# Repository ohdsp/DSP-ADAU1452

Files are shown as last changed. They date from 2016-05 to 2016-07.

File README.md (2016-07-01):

# [Open Hardware DSP Platform](http://www.ohdsp.org)
## ADAU145x DSP supporting ADAU1452, ADAU1451, and ADAU1450 devices
### Revision 2.0
###### DSP-ADAU1452 (KiCad 4.0.2-stable)
---
# README
### Disclaimer
Copyright Paul Janicki 2015

Licensed under the TAPR Open Hardware License (www.tapr.org/OHL)

This documentation is distributed WITHOUT ANY EXPRESS OR IMPLIED WARRANTY, INCLUDING OF MERCHANTABILITY, SATISFACTORY QUALITY AND FITNESS FOR A PARTICULAR PURPOSE.

### What is this repository for?

**Quick summary**

This is a simple self-bootable ADAU1450, ADAU1451, or ADAU1452 based DSP board with 4 I2S (TDM/left and right justified and more) input and 4 output connectors. When used with the ADAU1451 and ADAU1452 parts there are also optical and coaxial SPDIF input and output connectors. 

There is an I2C/SPI connector for connection to the Analog Devices SigmaStudio USBi to EZ-Board Adapter (ADZS-USBI2EZB) or anything that will do the same job (eg freeUSBi). The board also features master and slave SPI connectors for use with other OHDSP boards. The board has space for a self-boot EEPROM and so with the ADZS-USBI2EZB or compatible device the board can be programmed as you wish and will selfboot the last program written when enabled. 

This board forms the core of the open hardware DSP platform which is designed to be a highly customisable and flexible DSP platform. 

This repository contains the KiCad design files, manufacturing Gerber/drill files, and PDF/drawing files for this board.

### What is the project folder structure?
Most folder names are self explanatory. Starting from the top level: \
*DSP-ADAU1452*
+ *Bill of Materials*  - This contains the bill of materials in CVS, LibreOffice Calc and XML formats
+ *Drawings*
    + *PCB* - This contains SVG and PDF outputs of PCB copper layers and assembly drawings
    + *Schematics* - This contains the PDF schematic drawing
+ *Gerbers* - This contains the PCB Gerbers and drill drawings for manufacture, there is also a zip file ready to send to most manufacturers
+ *KiCad* - This contains the original KiCad schematic and PCB design files

### How do I get set up?

**Summary of set up**

1. Set your self up a directory on a local disk, something simple will make life easier (eg C:\Electronics on Windows as used here), but anywhere will do just fine.
2. Download the Kicad-Libs from [https://github.com/ohdsp/KiCad-Libs](https://github.com/ohdsp/KiCad-Libs) and place in C:\Electronics\Kicad-Libs (or your chosen folder) 
3. Create a OHDSP subdirectory in C:\Electronics (so C:\Electronics\OHDSP)
3. Download this project to C:\Electronics\OHDSP\DSP-ADAU1452
4. Fire up Kicad
5. Open the main project file C:\Electronics\OHDSP\DSP-ADAU1452\Schematics\DSP-ADAU1452.pro
6. (Optional) Setup Pcbnew component library as below.
7. Do as you wish with the project, just keep it under the TAPR Open Hardware License.

Make sure your git setup doesn't exclude files used in the project (like .LIB files) or things may go wrong down the line.

**KiCad Library Configuration**

Note that you need to setup a Pcbnew library, but the eeschema libraries should work without any changes if you followed the instructions above.

To setup Pcbnew libraries:

In Pcbnew go to Preferences -> Footprint Libraries Manager. Under Global Libraries tab in the top list check if there is a nickname "MyKiCadLibs-Footprints" (usually at the end of the list). If there is but it points to the wrong place then change the Library Path to point to MyKiCadLibs-Footprints (eg C:\Electronics\KiCad-Libs\MyKiCadLibs-Footprints.pretty) folder for your setup. If this is missing you can use "Append with Wizard", choose "Files on my computer", click next, browse to library location (eg C:\Electronics\KiCad-Libs\MyKiCadLibs-Footprints.pretty) and select the folder MyKiCadLibs-Footprints.pretty, click next, check the Status column states OK and the Format is KiCad (if not re-download the library) and click next, then select "To global library configuration..." and click Finish.

To setup eeschema component libraries:
Either from KiCad project window go to Tools -> Run Library Editor OR under eeschema, go to Tools -> Library Editor. Then Preferences -> Component Libraries.

The top section "Component Library Files" should ideally contain only two libraries, the "power" library that ships with KiCad and "MyKiCadLibs-Lib" available from above. To setup MyKiCadLibs-Lib as a relative path under the "User defined search path" click add. Browse to the location of KiCad-Libs you download above (eg C:\Electronics\KiCad-Libs) and click "Select Folder". Say yes to add a relative path. Under component library files click add, browse to the KiCad-libs again (eg C:\Electronics\KiCad-Libs), select file "MyKiCadLibs-Lib.lib" and click open. MyKiCadLibs-lib should appear in the component library list with no path as it will be using the user defined search path set in the box below.

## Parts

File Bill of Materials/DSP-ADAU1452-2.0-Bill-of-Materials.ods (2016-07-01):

DSP-ADAU1452-2.0 of Materials – Revision 2.0
25 May 2016
Reference | Quantity | Footprint | Value | Description | Voltage | Type | Tolerance | Size | Current | Power
C205 C214 C231 C250 C265 C304 C327 C401 C501 C504 | 10 | SMD-0805 | 100p | 'Ceramic capacitor | '50V | 'C0G | '5% | '0805 | ' | '
C206 C232 C251 C318 C324 C336 C403 | 7 | CAP-TH-D6.3mmP2.5mm | 220u | 'Low impedance aluminium electrolytic capacitor - Panasonic FC, FR or similar | '10V | '2.5mm pitch, 6.3mm diameter | ' | ' | ' | '
C207 C234 C267 C313 C315 C316 C322 C334 C405 C502 C505 | 11 | SMD-0805 | 22u | 'Ceramic capacitor | '10V | 'X5R | '20% | '0805 | ' | '
C201 C208 C210 C212 C218 C233 C235 C236 C239 C243 C253 C264 C302 C307 C310 C314 C317 C319 C320 C323 C326 C329 C333 C338 C402 C406 C412 C413 C414 C416 C417 C503 C506 | 33 | SMD-0805 | 100n | 'Ceramic capacitor | '50V | 'X7R | '10% | '0805 | ' | '
C209 C211 C216 C256 C266 C321 C325 C328 C337 C339 C404 C410 C411 | 13 | SMD-0805 | 10u | 'Ceramic capacitor | '10V | 'X5R | '20% | '0805 | ' | '
C213 C219 C223 C228 C237 C240 C242 C245 C246 C257 | 10 | SMD-0603 | 1u | 'Ceramic capacitor | '10V | 'X7R | '10% | '0603 | ' | '
C215 C221 C226 C229 C238 C241 C244 C247 C248 C258 C268 | 11 | SMD-0603 | 100n | 'Ceramic capacitor | '50V | 'X7R | '10% | '0603 | ' | '
C217 C222 C227 C230 C249 C260 | 6 | SMD-0603 | 10n | 'Ceramic capacitor | '50V | 'X7R | '10% | '0603 | ' | '
C224 | 1 | SMD-0603 | 5n6 | 'Ceramic capacitor | '50V | 'X7R | '10% | '0603 | ' | '
C225 | 1 | SMD-0603 | 150p | 'Ceramic capacitor | '50V | 'C0G | '5% | '0603 | ' | '
C252 | 1 | SMD-0805 | 22u | 'Ceramic capacitor | '10V | 'X5R | '20% | ' | ' | '
C254 C261 | 2 | SMD-0805 | 33p | 'Ceramic capacitor | '50V | 'C0G | '5% | '0805 | ' | '
C220 C263 C308 C415 | 4 | SMD-0805 | 10n | 'Ceramic capacitor | '50V | 'X7R | '10% | '0805 | ' | '
C303 C306 | 2 | CAP-TH-D6.3mmP2.5mm | 220u | 'Aluminium electrolytic capacitor | '16V | '2.5mm pitch, 6.3mm diameter | ' | ' | ' | '
C301 C305 C309 | 3 | SMD-0805 | 22u | 'Ceramic capacitor | '25V | 'X5R | '20% | '0805 | ' | '
C311 C312 | 2 | SMD-0805 | N/F | 'Ceramic capacitor | '16V | 'X7R | '10% | '0805 | ' | '
C407 C408 | 2 | SMD-0805 | N/F | 'Ceramic capacitor | '10V | 'X7R | '10% | '0805 | ' | '
CN401 CN402 | 2 | CONN_SIL_2_1MM | COAX | '1x2 2.54mm pitch pin header - use with 75Ohm coax | ' | ' | ' | ' | ' | '
D301 D302 | 2 | DIODE-SMA | B240A | 'B240A 2A 40V Schottky Rectifier - SMA (DO-214AC) | ' | ' | ' | ' | ' | '
D303 D305 D306 D307 D501 D502 D503 D504 D505 D506 D507 D508 D509 D510 D511 D512 | 16 | DIODE-SOD-123 | SS14L | 'SS14L 1A 40V Schottky rectifier - Sub-SMA (SOD-123) | ' | ' | ' | ' | ' | '
D304 | 1 | SMD-1206 | Green LED 1206 | 'Green LED - SMD - Vf 1.8V to 2.2V | ' | ' | ' | '1206 | ' | '
FID1 FID2 FID3 FID4 | 4 | FID-1MM-3MM | MNT_HOLE | 'Fiducial | ' | ' | ' | ' | ' | '
L201 L202 L203 L301 L401 | 5 | SMD-0805 | 600R@100MHz | 'Ferrite bead, current rating 1A or higher, 600R@100MHz | ' | ' | ' | '0805 | '=>1A | '
L302 | 1 | IND-TYS5040-HS | TYS50404R7N-10 | 'Laird Technologies TYS5040 4.7uH Inductor - 3A Irms, 3.5A Isat, 0.030ohm, 28MHz | ' | ' | ' | ' | '3A | '
MNT301 MNT302 MNT303 MNT304 | 4 | MNT_HOLE_3.2mm | MNT_HOLE | 'Mounting hole | ' | ' | ' | ' | ' | '
JP201 P202 P306 P307 | 4 | CONN_SIL_2_1MM | CONN_2x1 | '1x2 2.54mm pitch pin header | ' | ' | ' | ' | ' | '
JP401 P203 | 2 | CONN_SIL_3_1MM | CONN_3x1 | '1x3 2.54mm pitch pin header | ' | ' | ' | ' | ' | '
P304 | 1 | CONN-2WAY-2.54mm-3.81mm-SPACING | CONN_2x1 | '2 way screw terminal, any 2.54mm to 3.81mm pitch part | ' | ' | ' | ' | ' | '
P501 P502 P503 P504 P506 P507 P508 P509 P510 | 9 | CONN_DIL_2X5_BOX_1MM | CONN_02X05 | '2x5 2.54mm pitch box header | ' | ' | ' | ' | ' | '
P505 | 1 | CONN_DIL_2X6_1MM | CONN_02X06 | '2x6 2.54mm pitch box header | ' | ' | ' | ' | ' | '
P511 P512 | 2 | CONN_DIL_2X6_BOX_1MM | CONN_02X06 | '2x6 2.54mm pitch box header | ' | ' | ' | ' | ' | '
R201 R225 R542 R543 | 4 | SMD-0805 | 1k | 'Thick or thin film resistor | ' | ' | '1% | '0805 | ' | '100mW
R202 R215 R224 R237 R246 R303 R311 R401 R533 R534 | 10 | SMD-0805 | 47 | 'Thick or thin film resistor | ' | ' | '1% | '0805 | ' | '100mW
R203 R204 R205 R206 R207 R208 R209 R210 R220 R239 R243 R245 R501 R502 R503 R504 R505 R506 R507 R508 R509 R510 R511 R512 R513 R514 R515 R516 R568 R569 R570 R571 R572 R573 R574 R575 R576 R577 R578 R579 R580 R581 R582 R583 | 44 | SMD-0805 | N/F | 'Thick or thin film resistor | ' | ' | '1% | '0805 | ' | '100mW
R211 R227 R228 R229 R230 R233 R234 R235 R236 R248 R403 R404 R405 R406 R407 R413 R544 R545 R546 R547 R548 R549 R550 R551 R553 R554 R555 R557 R558 R559 R561 R562 R563 R565 R566 R567 | 36 | SMD-0805 | 75 | 'Thick or thin film resistor | ' | ' | '1% | '0805 | ' | '100mW
R217 | 1 | SMD-0805 | 12k | 'Thick or thin film resistor | ' | ' | '1% | '0805 | ' | '100mW
R218 | 1 | SMD-0805 | 3k3 | 'Thick or thin film resistor | ' | ' | '1% | '0805 | ' | '100mW
R219 | 1 | SMD-0603 | 4k3 | 'Thick or thin film resistor | ' | ' | '1% | '0603 | ' | '63mW
R221 | 1 | SMD-0805 | 3k | 'Thick or thin film resistor | ' | ' | '1% | '0805 | ' | '100mW
R222 | 1 | SMD-0805 | 3k6 | 'Thick or thin film resistor | ' | ' | '1% | '0805 | ' | '100mW
R212 R213 R214 R216 R223 R306 R517 R518 R519 R520 R521 R522 R523 R524 R525 R526 R527 R528 R529 R530 R531 R532 R541 R552 R556 R560 R564 R586 R587 | 29 | SMD-0805 | 0 | 'Thick or thin film resistor | ' | ' | '1% | '0805 | ' | '100mW
R226 R231 R241 R411 | 4 | SMD-0805 | 100 | 'Thick or thin film resistor | ' | ' | '1% | '0805 | ' | '100mW
R232 | 1 | SMD-0805 | 100k | 'Thick or thin film resistor | ' | ' | '1% | '0805 | ' | '100mW
R238 R240 R242 R302 R402 R408 R409 | 7 | SMD-0805 | 10k | 'Thick or thin film resistor | ' | ' | '1% | '0805 | ' | '100mW
R244 R247 R310 R584 R585 | 5 | SMD-0805 | 1 | 'Thick or thin film resistor | ' | ' | '1% | '0805 | ' | '100mW
R301 | 1 | SMD-0805 | 16k | 'Thick or thin film resistor | ' | ' | '1% | '0805 | ' | '100mW
R304 | 1 | SMD-0805 | 24k | 'Thick or thin film resistor | ' | ' | '1% | '0805 | ' | '100mW
R305 | 1 | SMD-0805 | 15k | 'Thick or thin film resistor | ' | ' | '1% | '0805 | ' | '100mW
R309 | 1 | SMD-0805 | 470 | 'Thick or thin film resistor | ' | ' | '1% | '0805 | ' | '100mW
R410 | 1 | SMD-0805 | 360 | 'Thick or thin film resistor | ' | ' | '1% | '0805 | ' | '100mW
R412 | 1 | SMD-0805 | 91 | 'Thick or thin film resistor | ' | ' | '1% | '0805 | ' | '100mW
R535 R536 R537 R538 R539 R540 | 6 | SMD-0805 | 4k7 | 'Thick or thin film resistor | ' | ' | '1% | '0805 | ' | '100mW
SW201 | 1 | SW_TACT_SMD | SWITCH | '6mm x 6mm SMD tactile switch - e.g. TE FSM2JSMA | ' | ' | ' | ' | ' | '
TP201 TP501 TP502 TP503 TP504 TP505 TP506 TP507 TP508 TP509 TP510 TP511 TP512 TP513 TP514 TP515 TP516 TP517 TP518 TP519 TP520 TP521 TP522 TP523 TP524 TP525 TP526 TP527 TP528 | 29 | TP-TH-1mm | PIN | Test Point (Through hole)
TP204 TP205 | 2 | TP-1mm | PIN | Test Point (SMD)
TP206 | 1 | TP-2mm | PIN | Test Point (SMD)
U201 | 1 | IC-LFCSP72-HANDFIT | ADAU1452WBCPZ | 'SigmaDSP Digital Audio Processor - Use ADAU1452, ADAU1451, or ADAU1450 | ' | ' | ' | ' | ' | '
U202 | 1 | IC_SOIC_8 | ADM13307-5ARZ | 'Triple Processor Supervisors - Use ADM13307-5ARZ only (Sense1 = 3v3, Sense2/3=Adj) | ' | ' | ' | ' | ' | '
U203 | 1 | IC-SC70-6 | NC7WZ17P6X | 'UHS Dual Buffer with Schmitt Trigger Inputs | ' | ' | ' | ' | ' | '
U204 | 1 | IC_DIP_8 | 25AA1024 | '1 Mbit SPI Bus Serial EEPROM - Fit 8 pin DIP socket | ' | ' | ' | ' | ' | '
U301 | 1 | IC-SOT23-6 | ADP2301AUJZ | '1.2 A, 20 V, 700 kHz/1.4 MHz, Nonsynchronous Step-Down Regulator | ' | ' | ' | ' | ' | '
U302 | 1 | IC-SOT-223 | TLV1117LV33DCY | 'TLV1117LV 1-A, Positive Fixed-Voltage, Low-Dropout Regulator - Fixed 3V3 | ' | ' | ' | ' | ' | '
U303 | 1 | IC-SOT-223 | TLV1117LV12DCY | 'TLV1117LV 1-A, Positive Fixed-Voltage, Low-Dropout Regulator - Fixed 1V2 | ' | ' | ' | ' | ' | '
U401 | 1 | IC-SC70-6 | NC7WZ16P6X | 'UHS Dual Buffer | ' | ' | ' | ' | ' | '
U402 | 1 | IC_SPDIF_OPTO | IC-SPDIF-RX-OPTO | 'TOSLINK receiver e.g. CLIFF FC684205R | ' | ' | ' | ' | ' | '
U403 | 1 | IC_SPDIF_OPTO | IC-SPDIF-TX-OPTO | 'TOSLINK transmitter e.g. CLIFF FC684205T | ' | ' | ' | ' | ' | '
U404 | 1 | IC_SOIC_14 | 74HC04 | '74HC04 Hex Inverter - SOIC-14 | ' | ' | ' | ' | ' | '
U501 U502 | 2 | IC_SOIC_8 | NB3L553 | 'On Semi - 1:4 Clock Fanout Buffer | ' | ' | ' | ' | ' | '
X201 | 1 | XTAL_HC49_TH | 24M576 | 'HC49 Crystal, 24.576MHz, 18pF | ' | ' | ' | ' | ' | '

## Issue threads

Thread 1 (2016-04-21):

Strange connection

mr-miky, 2016-04-21:
I think there is something strange in the supply section.
**R307** and **R308** may not be **0 ohm** otherwise you short the **+3V3** to **GND**

ohdsp, 2016-04-25:
Yes, correct, R308 should be not fitted.

Date: Thu, 21 Apr 2016 12:39:55 -0700
From: notifications@github.com
To: DSP-ADAU1452-StandAlone@noreply.github.com
CC:
Subject: [ohdsp/DSP-ADAU1452-StandAlone] Strange connection (#1)

I think there is something strange in the supply section.

R307 and R308 may not be 0 ohm otherwise you short the +3V3 to GND

—
You are receiving this because you are subscribed to this thread.
Reply to this email directly or view it on GitHub

ohdsp, 2016-04-27:
I am close to finishing Revision 2.0 of this board which has a number of changes. One of these changes is U302 being replaced with a lower cost part which has no adjust pin for setting the voltage and so these resistor no longer exist.

Closed 2016-04-27.

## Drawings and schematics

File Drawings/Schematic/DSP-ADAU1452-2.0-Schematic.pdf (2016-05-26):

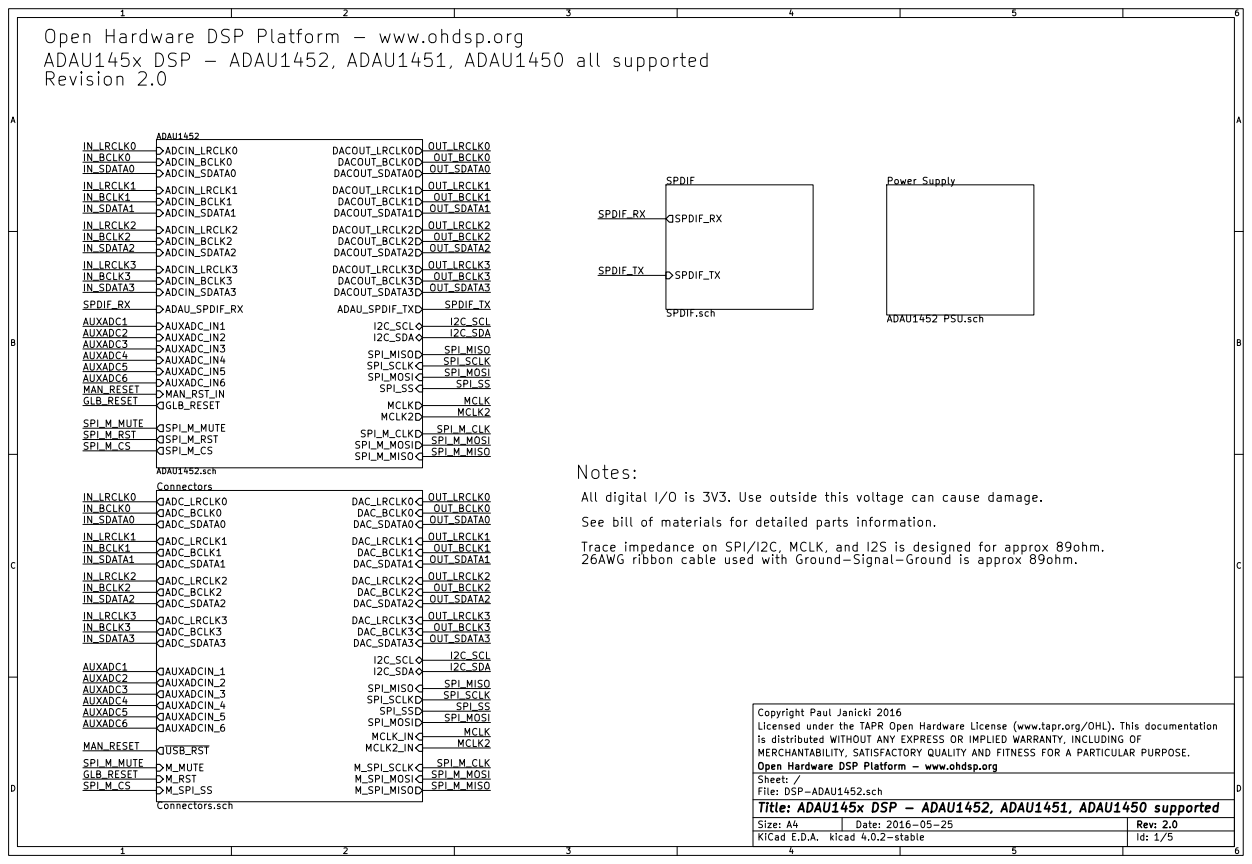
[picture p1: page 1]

Open Hardware DSP Platform - www.ohdsp.org
ADAU145x DSP - ADAU1452, ADAU1451, ADAU1450 all supported
Revision 2.0

IN_BCLK0
IN_SDATA0

IN_BCLK1 | OUT_BCLK1
IN_SDATA1 | OUT_SDATA1

IN_BCLK2 | OUT_BCLK2
IN_SDATA2 | OUT_SDATA2

IN_BCLK3 | OUT_BCLK3
IN_SDATA3 | OUT_SDATA3

All digital I/O is 3V3. Use outside this voltage can cause damage.
See bill of materials for detailed parts information.
Trace impedance on SPI/I2C, MCLK, and I2S is designed for approx 89ohm.
26AWG ribbon cable used with Ground-Signal-Ground is approx 89ohm.

IN_SDATA0 | OUT_SDATA0

IN_BCLK2
IN_SDATA2

IN_BCLK3
IN_SDATA3

Copyright Paul Janicki 2016
Licensed under the TAPR Open Hardware License (www.tapr.org/OHL). This documentation
is distributed WITHOUT ANY EXPRESS OR IMPLIED WARRANTY, INCLUDING OF
MERCHANTABILITY, SATISFACTORY QUALITY AND FITNESS FOR A PARTICULAR PURPOSE.
File: DSP-ADAU1452.sch Sheet: / Open Hardware DSP Platform - www.ohdsp.org

SPI_M_MOSI
SPI_M_MISO

Id: 1/5 Title: ADAU145x DSP - ADAU1452, ADAU1451, ADAU1450 supported

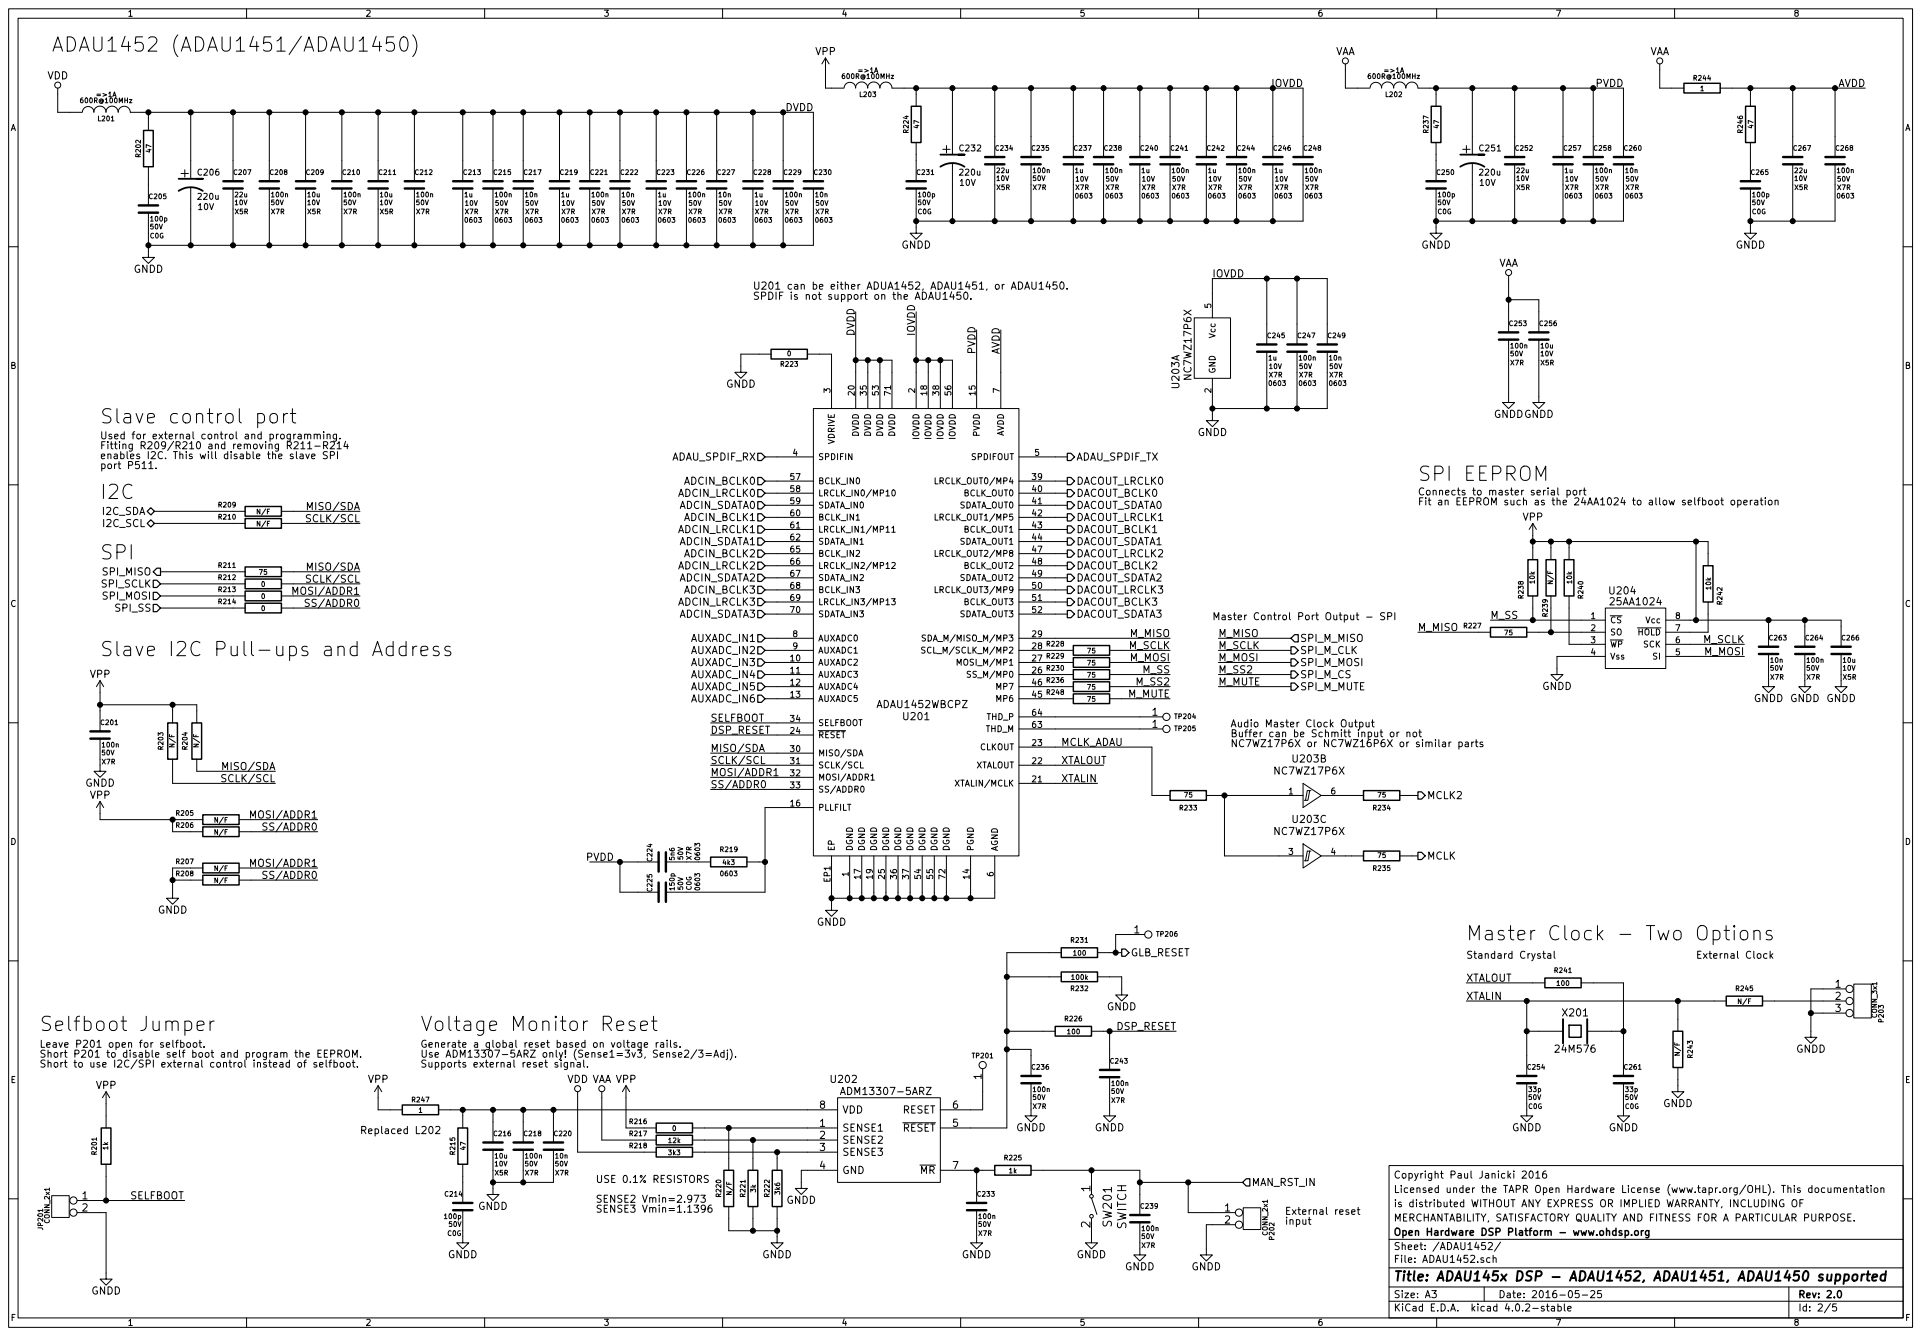
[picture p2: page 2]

U201 can be either ADUA1452, ADAU1451, or ADAU1450.
SPDIF is not support on the ADAU1450.

Used for external control and programming.
Fitting R209/R210 and removing R211-R214
enables I2C. This will disable the slave SPI port P511.

Connects to master serial port
Fit an EEPROM such as the 24AA1024 to allow selfboot operation

Audio Master Clock Output
Buffer can be Schmitt input or not

Copyright Paul Janicki 2016 DGND

Leave P201 open for selfboot.

Use ADM13307-5ARZ only! (Sense1=3v3, Sense2/3=Adj).
Supports external reset signal.

Licensed under the TAPR Open Hardware License (www.tapr.org/OHL). This documentation
is distributed WITHOUT ANY EXPRESS OR IMPLIED WARRANTY, INCLUDING OF
MERCHANTABILITY, SATISFACTORY QUALITY AND FITNESS FOR A PARTICULAR PURPOSE.
File: ADAU1452.sch Sheet: /ADAU1452/ Open Hardware DSP Platform - www.ohdsp.org

Id: 2/5 Title: ADAU145x DSP - ADAU1452, ADAU1451, ADAU1450 supported

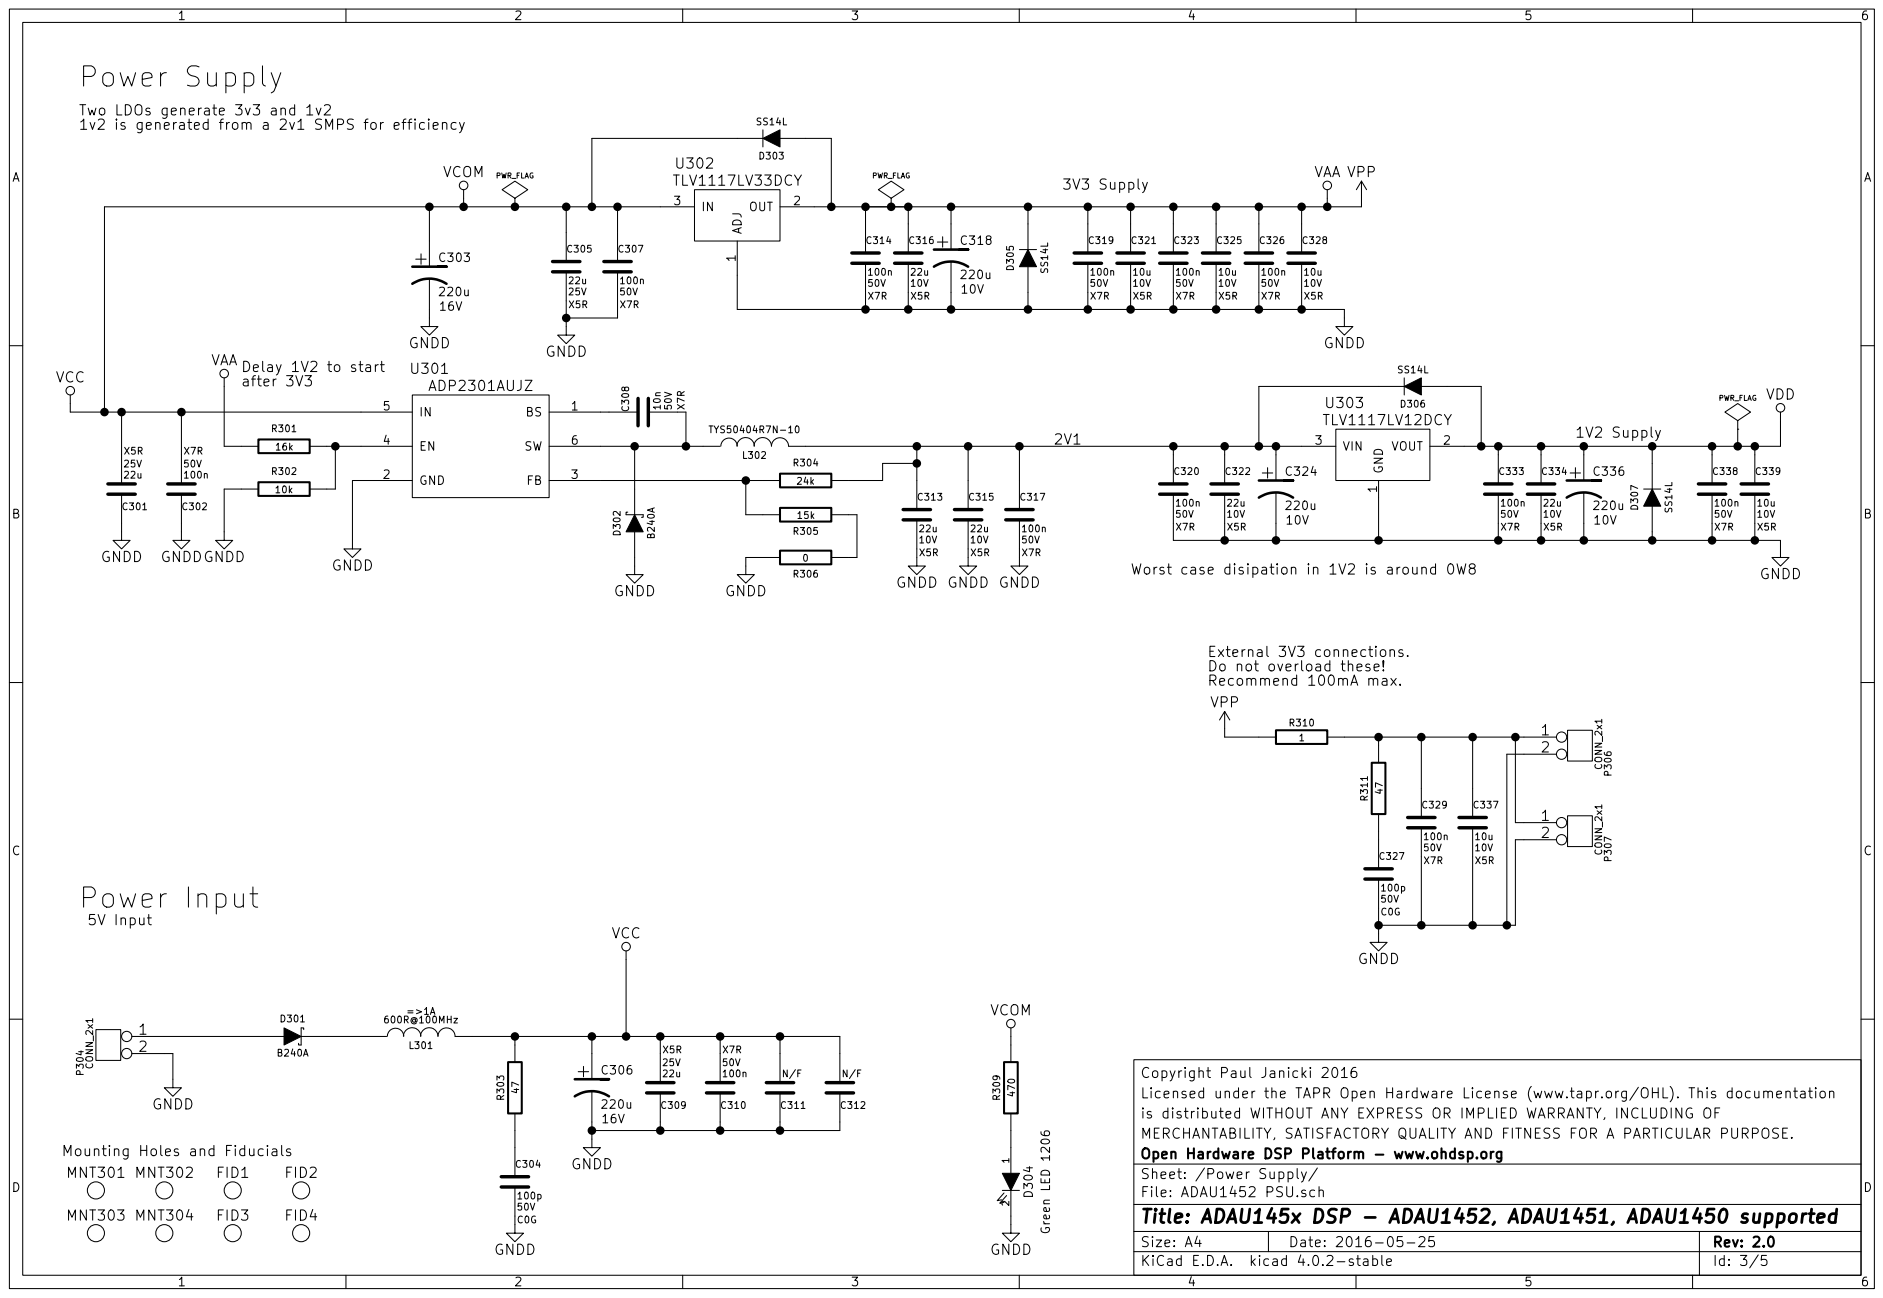
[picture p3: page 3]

Two LDOs generate 3v3 and 1v2
1v2 is generated from a 2v1 SMPS for efficiency

Worst case disipation in 1V2 is around 0W8 GND

Copyright Paul Janicki 2016
Licensed under the TAPR Open Hardware License (www.tapr.org/OHL). This documentation
is distributed WITHOUT ANY EXPRESS OR IMPLIED WARRANTY, INCLUDING OF
MERCHANTABILITY, SATISFACTORY QUALITY AND FITNESS FOR A PARTICULAR PURPOSE.
Open Hardware DSP Platform - www.ohdsp.org
File: ADAU1452 PSU.sch Sheet: /Power Supply/
Id: 3/5 Title: ADAU145x DSP - ADAU1452, ADAU1451, ADAU1450 supported

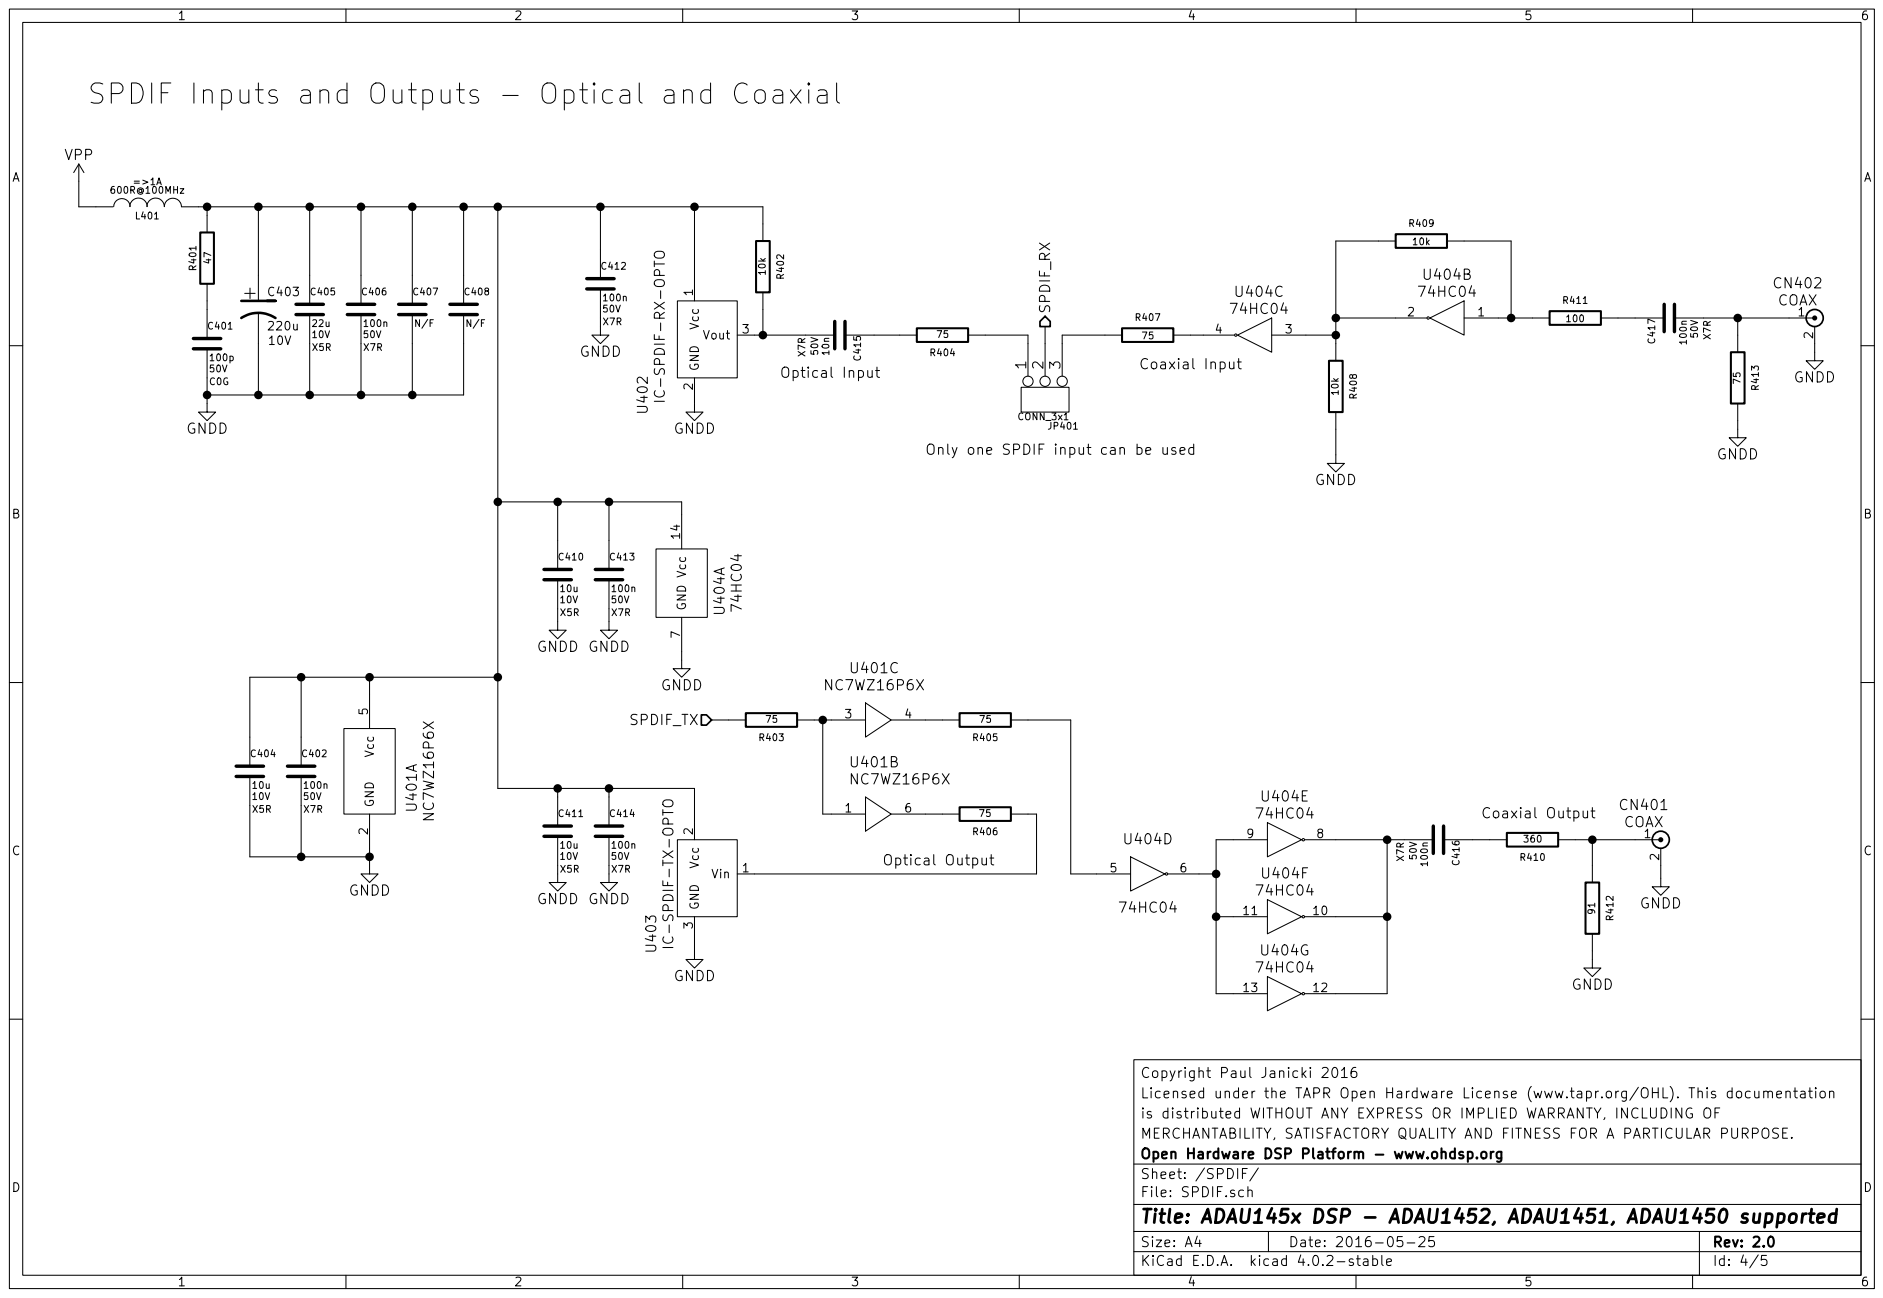
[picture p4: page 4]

VPPSPDIF Inputs and Outputs - Optical and Coaxial Vcc 1 GND

2 Vout 3 U402IC-SPDIF-RX-OPTO

3 U403 IC-SPDIF-TX-OPTO

Copyright Paul Janicki 2016
Licensed under the TAPR Open Hardware License (www.tapr.org/OHL). This documentation
is distributed WITHOUT ANY EXPRESS OR IMPLIED WARRANTY, INCLUDING OF
MERCHANTABILITY, SATISFACTORY QUALITY AND FITNESS FOR A PARTICULAR PURPOSE.
File: SPDIF.sch Sheet: /SPDIF/ Open Hardware DSP Platform - www.ohdsp.org

Id: 4/5 Title: ADAU145x DSP - ADAU1452, ADAU1451, ADAU1450 supported

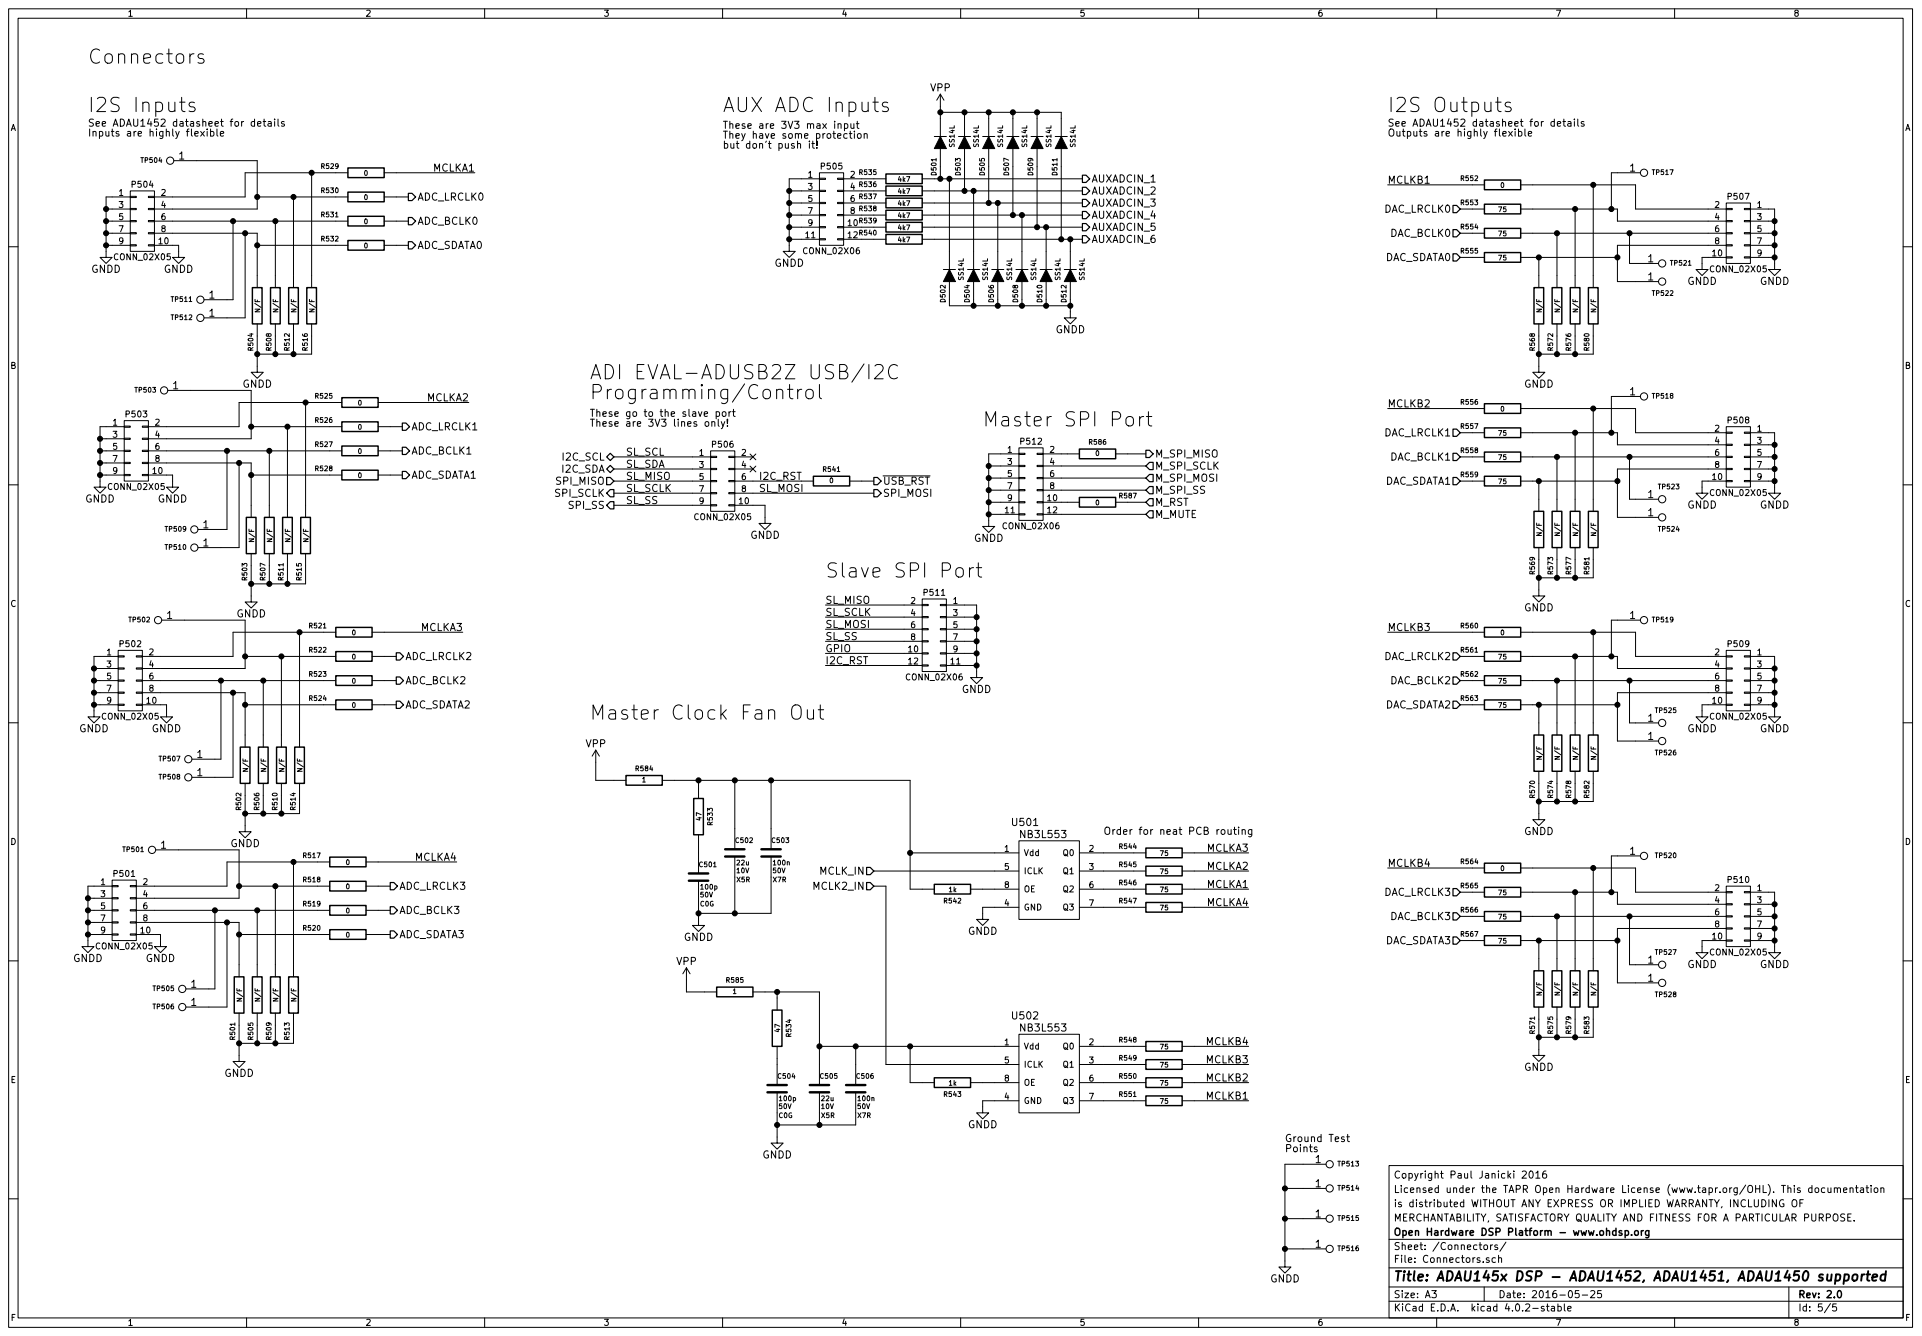
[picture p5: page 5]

See ADAU1452 datasheet for details
Inputs are highly flexible

These are 3V3 max input
They have some protection
but don't push it!

These go to the slave port

These are 3V3 lines only! ADC_LRCLK1

Ground Test Points Master Clock Fan Out

Order for neat PCB routing

Copyright Paul Janicki 2016
Licensed under the TAPR Open Hardware License (www.tapr.org/OHL). This documentation
is distributed WITHOUT ANY EXPRESS OR IMPLIED WARRANTY, INCLUDING OF
MERCHANTABILITY, SATISFACTORY QUALITY AND FITNESS FOR A PARTICULAR PURPOSE.
File: Connectors.sch Sheet: /Connectors/ Open Hardware DSP Platform - www.ohdsp.org

Id: 5/5 Title: ADAU145x DSP - ADAU1452, ADAU1451, ADAU1450 supported

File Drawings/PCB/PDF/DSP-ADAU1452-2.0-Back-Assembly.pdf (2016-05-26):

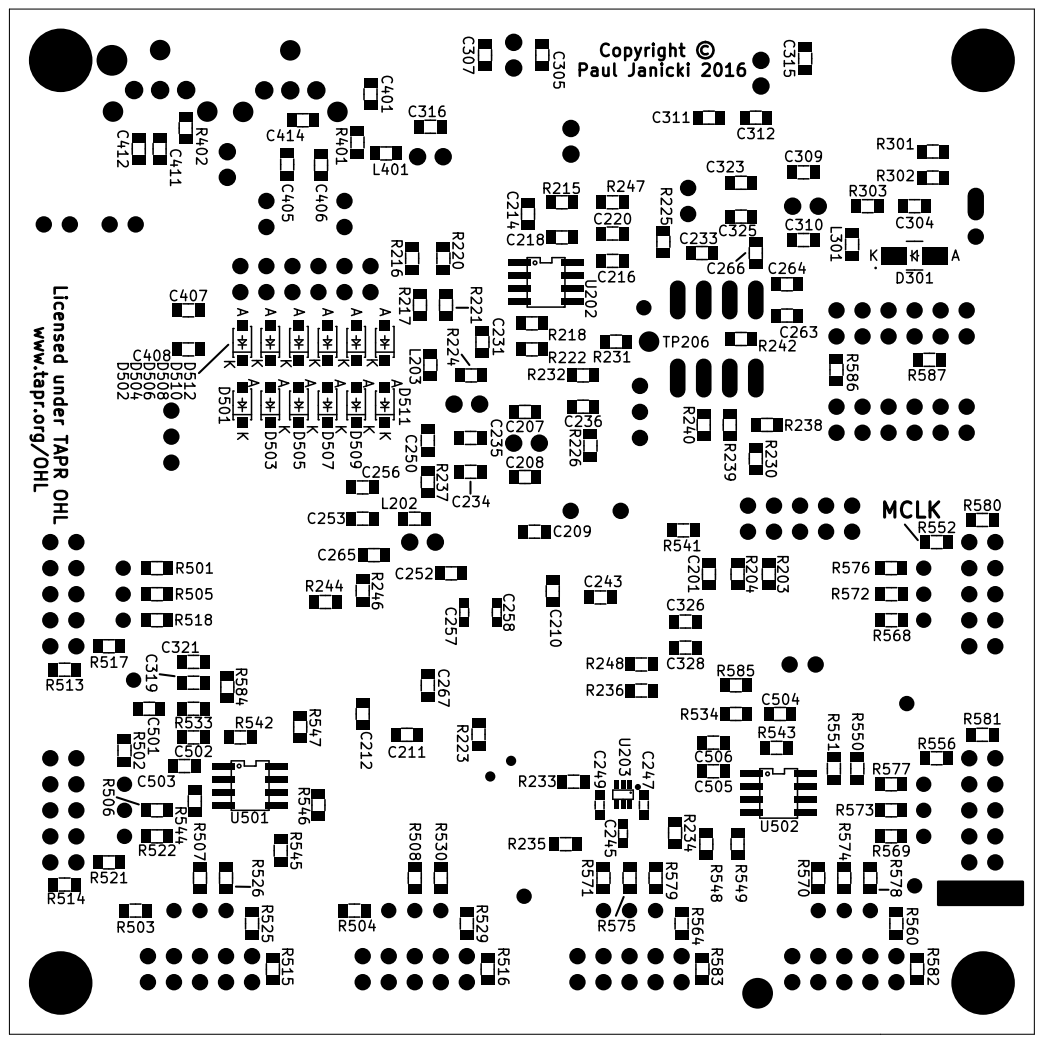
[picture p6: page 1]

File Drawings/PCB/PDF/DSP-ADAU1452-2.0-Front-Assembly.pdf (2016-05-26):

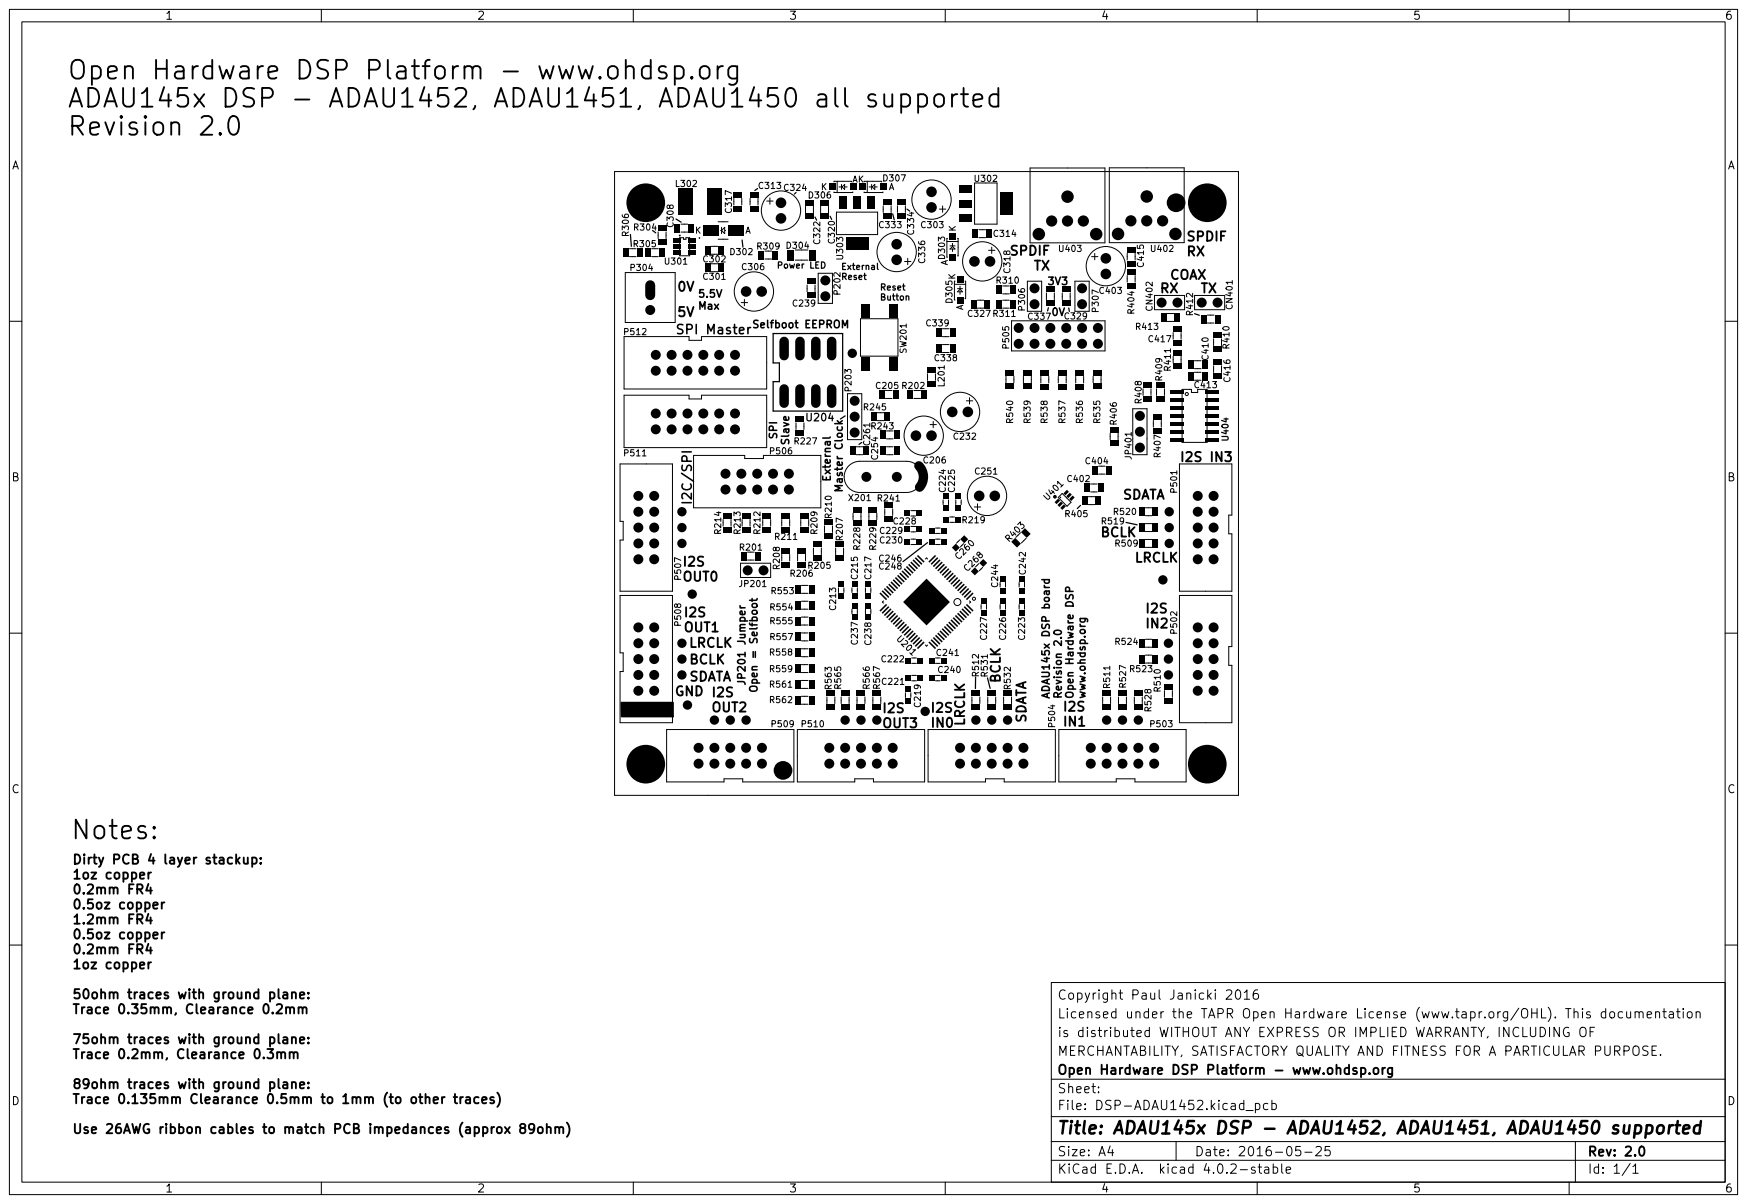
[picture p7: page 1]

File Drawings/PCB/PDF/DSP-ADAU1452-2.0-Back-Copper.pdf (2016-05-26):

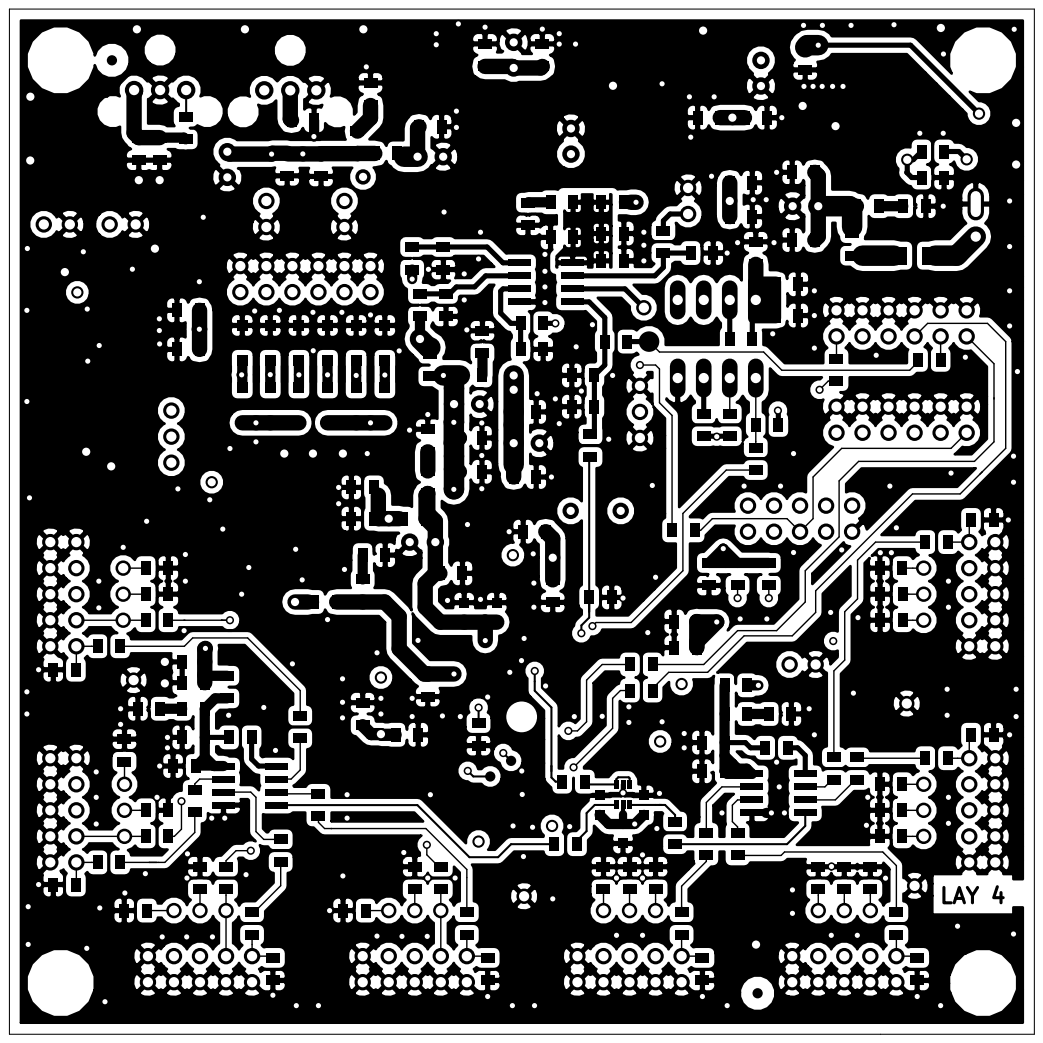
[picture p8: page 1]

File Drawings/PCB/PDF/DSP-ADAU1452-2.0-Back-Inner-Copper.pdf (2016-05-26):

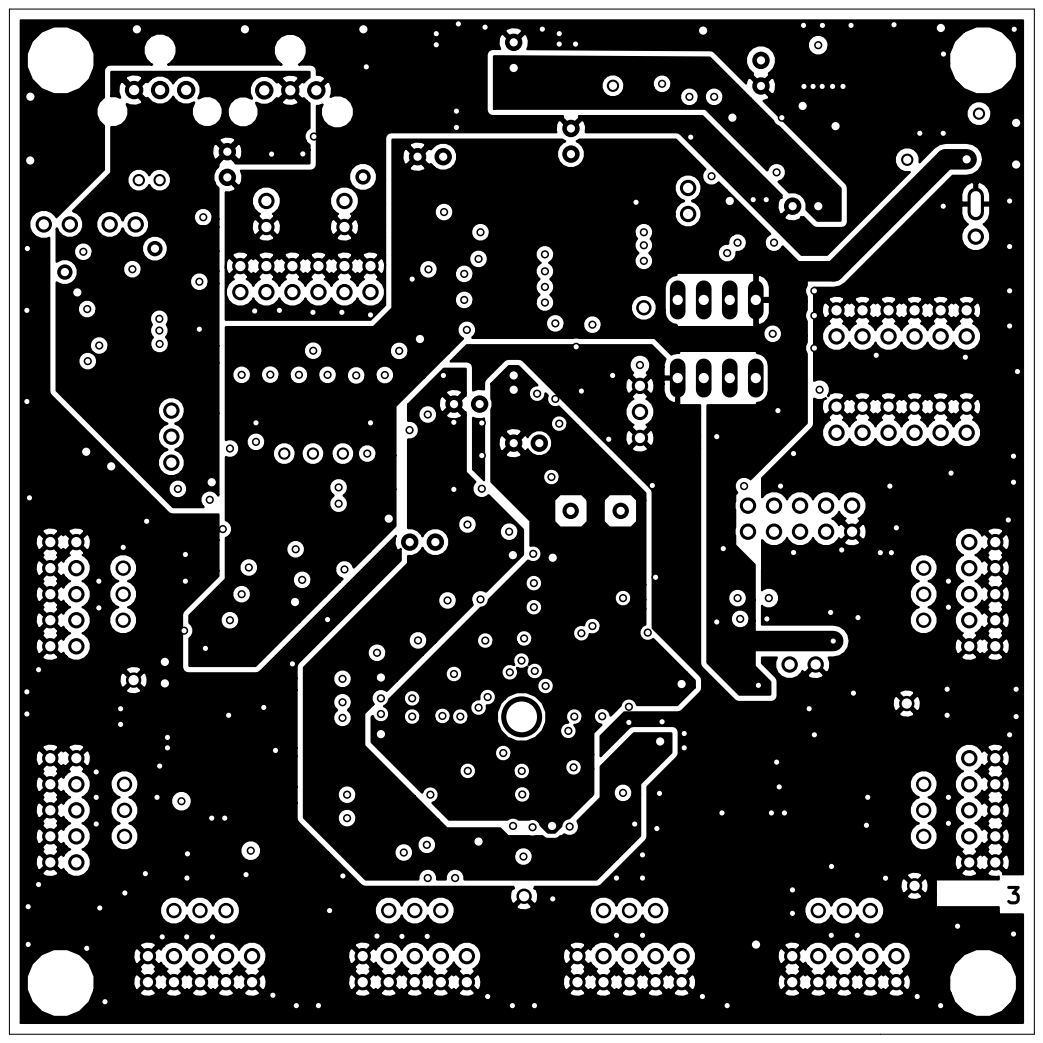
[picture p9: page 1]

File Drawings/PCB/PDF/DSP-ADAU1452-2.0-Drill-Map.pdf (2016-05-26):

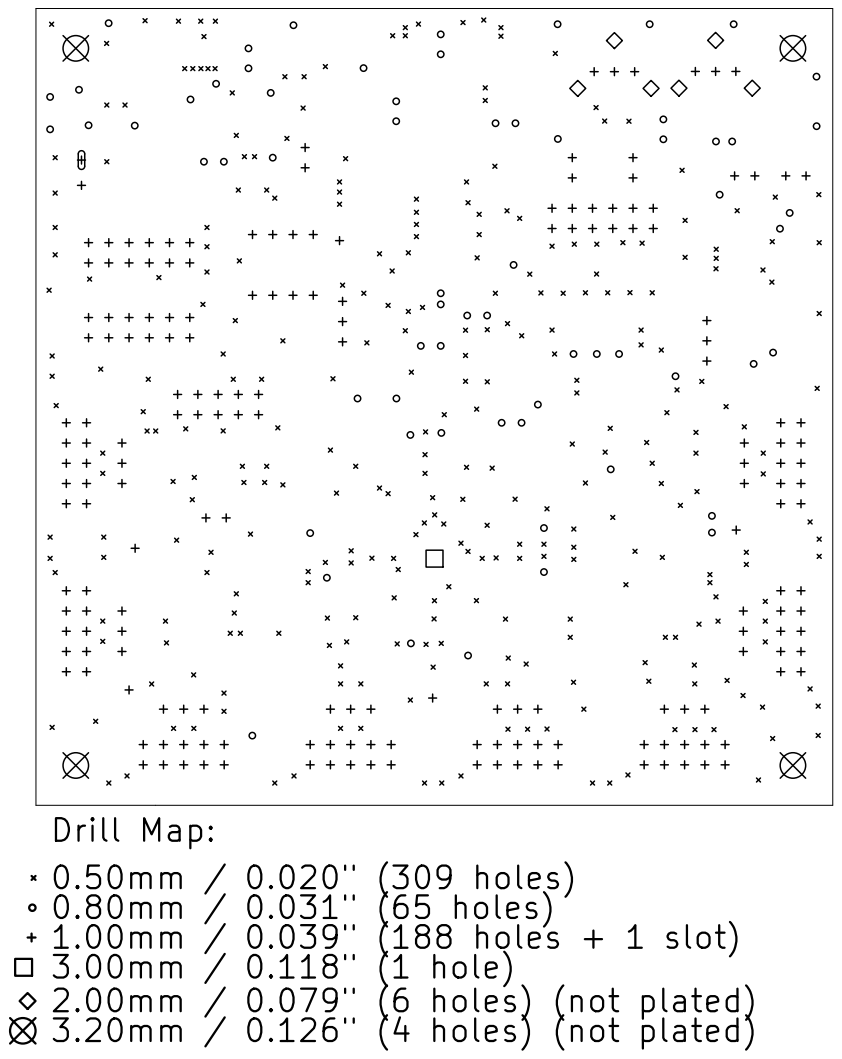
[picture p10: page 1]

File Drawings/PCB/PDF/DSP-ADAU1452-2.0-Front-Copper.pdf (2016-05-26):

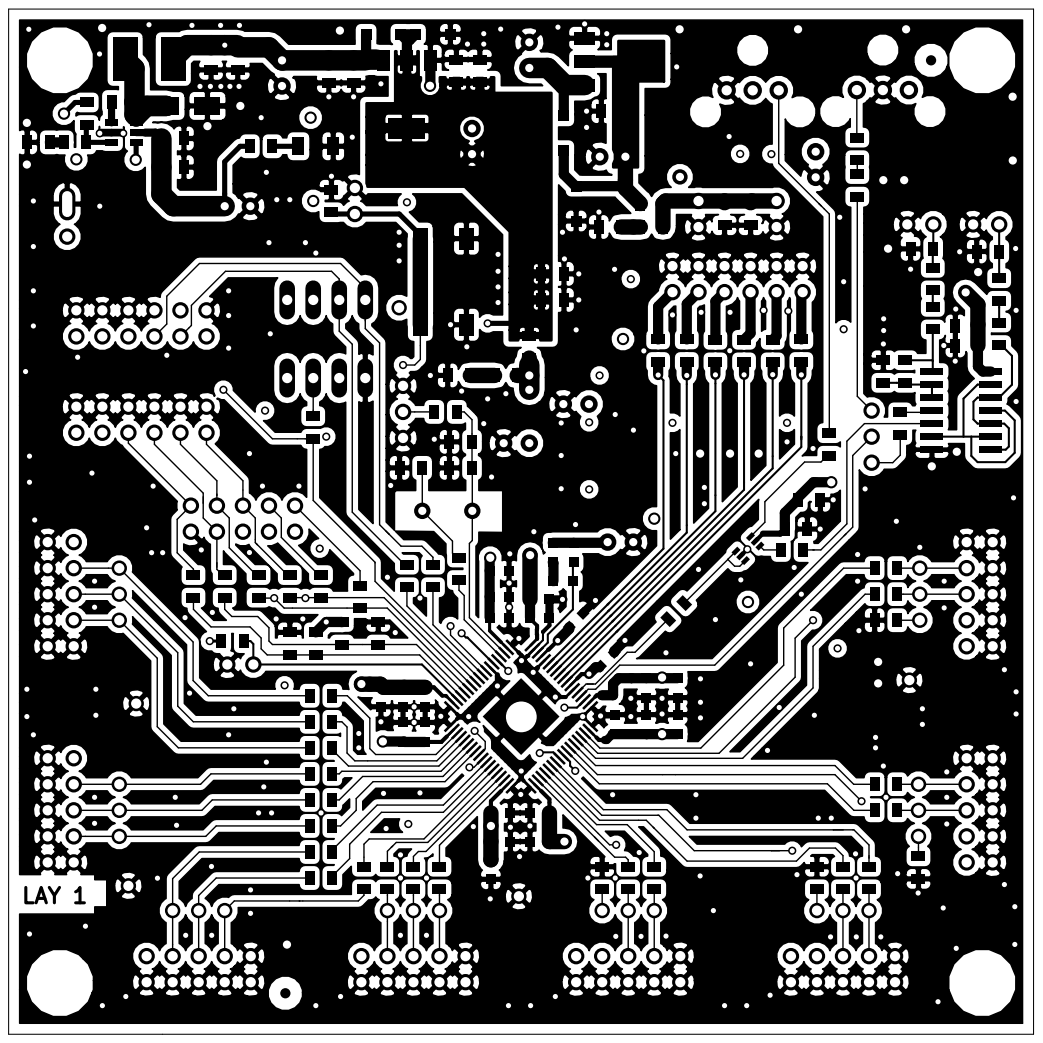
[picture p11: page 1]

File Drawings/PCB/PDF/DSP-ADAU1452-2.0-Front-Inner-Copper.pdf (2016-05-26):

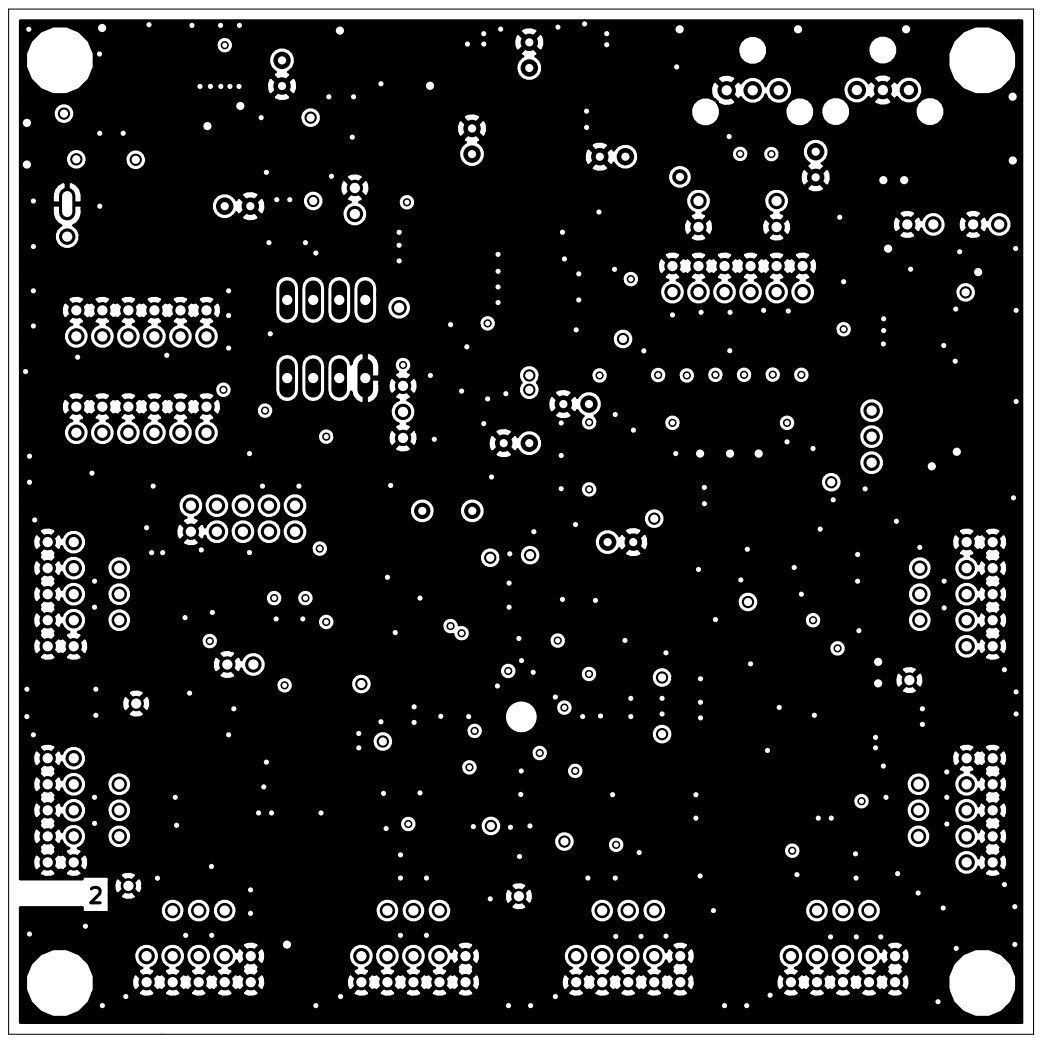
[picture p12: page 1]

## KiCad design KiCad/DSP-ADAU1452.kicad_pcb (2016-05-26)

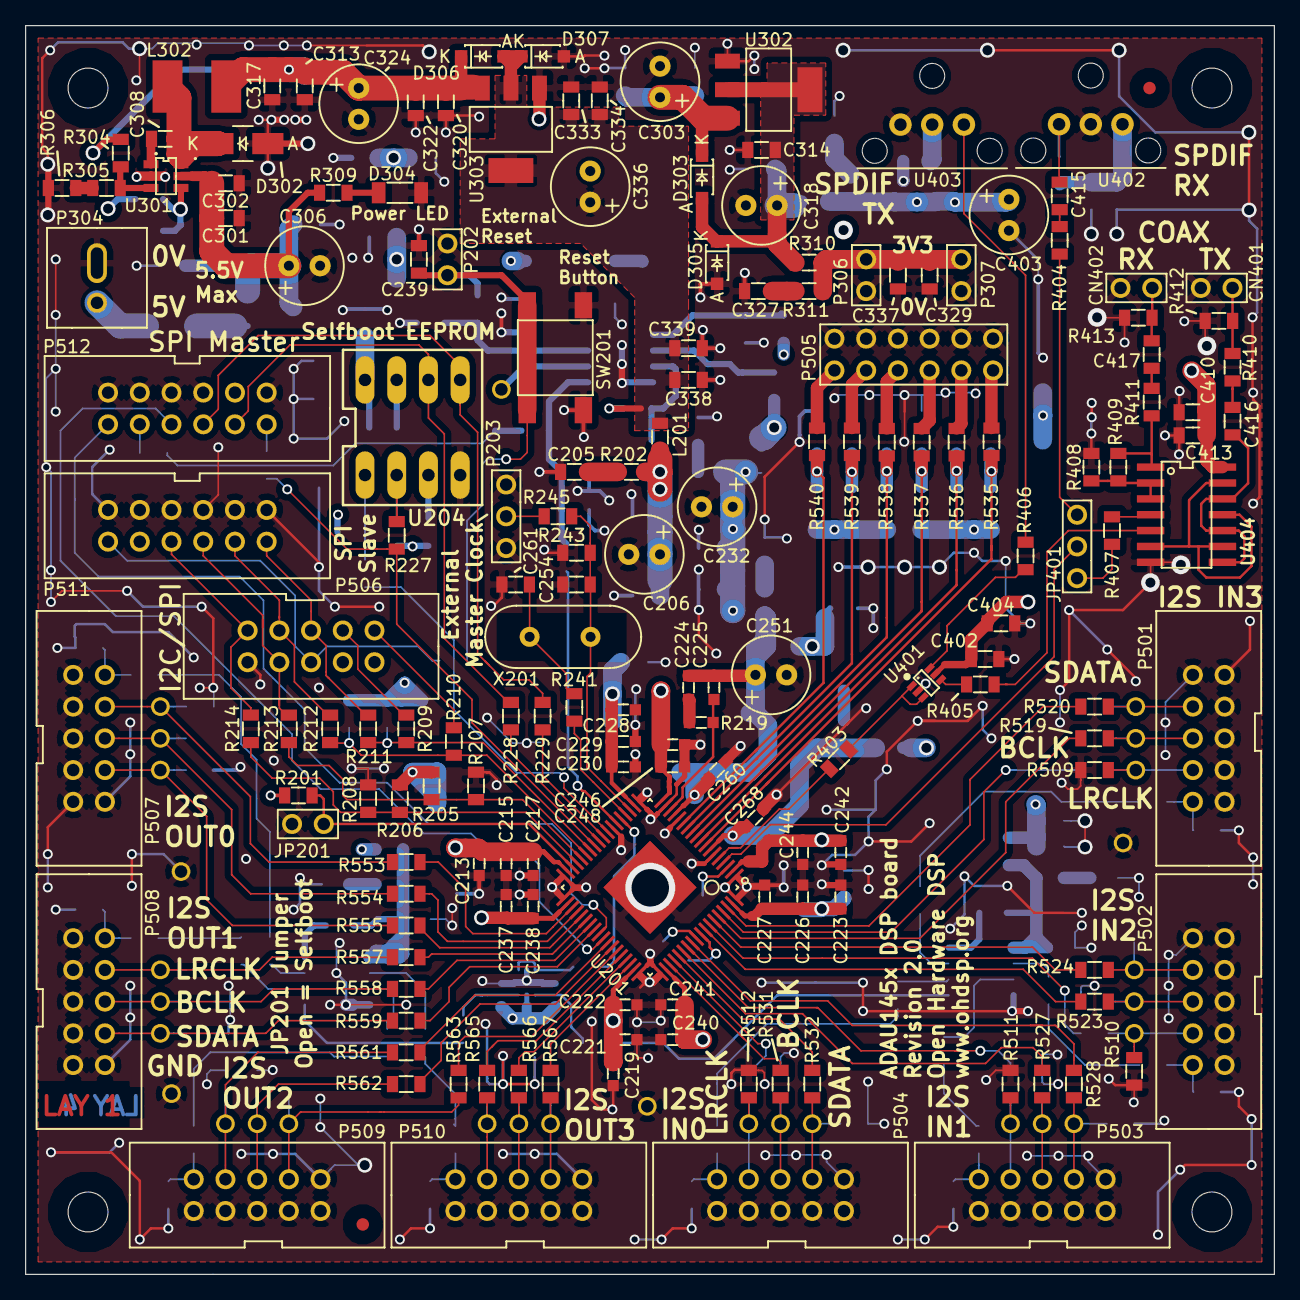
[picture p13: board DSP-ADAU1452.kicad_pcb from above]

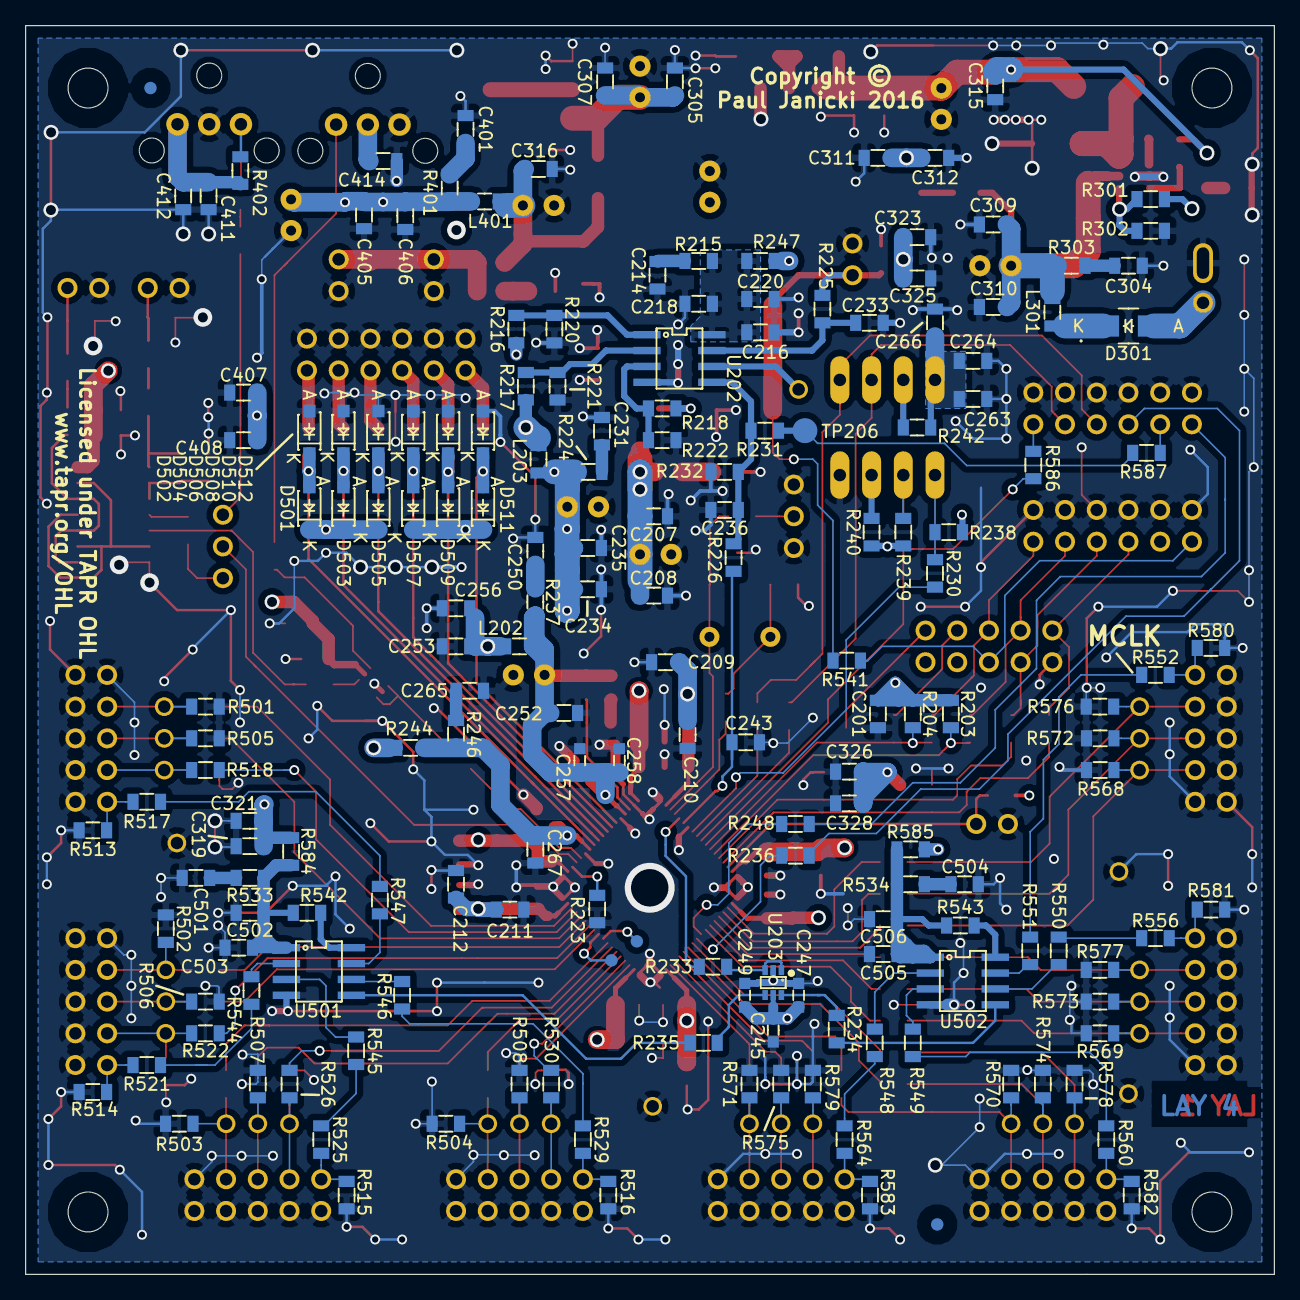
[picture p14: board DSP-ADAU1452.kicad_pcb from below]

Board: 4 copper layers, 100.0 x 100.0 mm, 377 parts (177 on the bottom side), 190 nets.

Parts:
C201, C208, C210, C212, C218, C233, C235, C236, C239, C243, C253, C264, C302, C307, C310, C314, C317, C319, C320, C323, C326, C329, C333, C338, C402, C406, C412, C413, C414, C416, C417, C503, C506: 100n; SMD-0805
C205, C214, C231, C250, C265, C304, C327, C401, C501, C504: 100p; SMD-0805
C206, C232, C251, C303, C306, C318, C324, C336, C403: 220u; CAP-TH-D6.3mmP2.5mm
C207, C234, C252, C267, C301, C305, C309, C313, C315, C316, C322, C334, C405, C502, C505: 22u; SMD-0805
C209, C211, C216, C256, C266, C321, C325, C328, C337, C339, C404, C410, C411: 10u; SMD-0805
C213, C219, C223, C228, C237, C240, C242, C245, C246, C257: 1u; SMD-0603
C215, C221, C226, C229, C238, C241, C244, C247, C248, C258, C268: 100n; SMD-0603
C217, C222, C227, C230, C249, C260: 10n; SMD-0603
C220, C263, C308, C415: 10n; SMD-0805
C224: 5n6; SMD-0603
C225: 150p; SMD-0603
C254, C261: 33p; SMD-0805
C311, C312, C407, C408: N/F; SMD-0805
CN401, CN402: COAX; CONN_SIL_2_1MM
D301, D302: B240A; DIODE-SMA
D303, D305, D306, D307, D501, D502, D503, D504, D505, D506, D507, D508, D509, D510, D511, D512: SS14L; DIODE-SOD-123
D304: Green LED 1206; SMD-1206
FID1, FID2, FID3, FID4: MNT_HOLE; FID-1MM-3MM
JP201: CONN_2x1; CONN_SIL_2_1MM
JP401: CONN_3x1; CONN_SIL_3_1MM
L201, L202, L203, L301, L401: 600R@100MHz; SMD-0805
L302: TYS50404R7N-10; IND-TYS5040-HS
MNT301, MNT302, MNT303, MNT304: MNT_HOLE; MNT_HOLE_3.2mm
P202, P306, P307: CONN_2x1; CONN_SIL_2_1MM
P203: CONN_3x1; CONN_SIL_3_1MM
P304: CONN_2x1; CONN-2WAY-2.54mm-3.81mm-SPACING
P501, P502, P503, P504, P506, P507, P508, P509, P510: CONN_02X05; CONN_DIL_2X5_BOX_1MM
P505: CONN_02X06; CONN_DIL_2X6_1MM
P511, P512: CONN_02X06; CONN_DIL_2X6_BOX_1MM
R201, R225, R542, R543: 1k; SMD-0805
R202, R215, R224, R237, R246, R303, R311, R401, R533, R534: 47; SMD-0805
R203, R204, R205, R206, R207, R208, R209, R210, R220, R239, R243, R245, R501, R502, R503, R504, R505, R506, R507, R508, R509, R510, R511, R512, R513, R514, R515, R516, R568, R569, R570, R571, R572, R573, R574, R575, R576, R577, R578, R579, R580, R581, R582, R583: N/F; SMD-0805
R211, R227, R228, R229, R230, R233, R234, R235, R236, R248, R403, R404, R405, R406, R407, R413, R544, R545, R546, R547, R548, R549, R550, R551, R553, R554, R555, R557, R558, R559, R561, R562, R563, R565, R566, R567: 75; SMD-0805
R212, R213, R214, R216, R223, R306, R517, R518, R519, R520, R521, R522, R523, R524, R525, R526, R527, R528, R529, R530, R531, R532, R541, R552, R556, R560, R564, R586, R587: 0; SMD-0805
R217: 12k; SMD-0805
R218: 3k3; SMD-0805
R219: 4k3; SMD-0603
R221: 3k; SMD-0805
R222: 3k6; SMD-0805
R226, R231, R241, R411: 100; SMD-0805
R232: 100k; SMD-0805
R238, R240, R242, R302, R402, R408, R409: 10k; SMD-0805
R244, R247, R310, R584, R585: 1; SMD-0805
R301: 16k; SMD-0805
R304: 24k; SMD-0805
R305: 15k; SMD-0805
R309: 470; SMD-0805
R410: 360; SMD-0805
R412: 91; SMD-0805
R535, R536, R537, R538, R539, R540: 4k7; SMD-0805
SW201: SWITCH; SW_TACT_SMD
TP201, TP501, TP502, TP503, TP504, TP505, TP506, TP507, TP508, TP509, TP510, TP511, TP512, TP513, TP514, TP515, TP516, TP517, TP518, TP519, TP520, TP521, TP522, TP523, TP524, TP525, TP526, TP527, TP528: PIN; TP-TH-1mm
TP204, TP205: PIN; TP-1mm
TP206: PIN; TP-2mm
U201: ADAU1452WBCPZ; IC-LFCSP72-HANDFIT
U202: ADM13307-5ARZ; IC_SOIC_8
U203: NC7WZ17P6X; IC-SC70-6
U204: 25AA1024; IC_DIP_8
U301: ADP2301AUJZ; IC-SOT23-6
U302: TLV1117LV33DCY; IC-SOT-223
U303: TLV1117LV12DCY; IC-SOT-223
U401: NC7WZ16P6X; IC-SC70-6
U402: IC-SPDIF-RX-OPTO; IC_SPDIF_OPTO
U403: IC-SPDIF-TX-OPTO; IC_SPDIF_OPTO
U404: 74HC04; IC_SOIC_14
U501, U502: NB3L553; IC_SOIC_8
X201: 24M576; XTAL_HC49_TH

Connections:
/ADAU1452/ADAU_SPDIF_RX: JP401.2, U201.4
/ADAU1452/ADAU_SPDIF_TX: R403.2, U201.5
/ADAU1452/ADCIN_BCLK0: R531.2, U201.57
/ADAU1452/ADCIN_BCLK1: R527.2, U201.60
/ADAU1452/ADCIN_BCLK2: R523.2, U201.65
/ADAU1452/ADCIN_BCLK3: R519.2, U201.68
/ADAU1452/ADCIN_LRCLK0: R530.2, U201.58
/ADAU1452/ADCIN_LRCLK1: R526.2, U201.61
/ADAU1452/ADCIN_LRCLK2: R522.2, U201.66
/ADAU1452/ADCIN_LRCLK3: R518.2, U201.69
/ADAU1452/ADCIN_SDATA0: R532.2, U201.59
/ADAU1452/ADCIN_SDATA1: R528.2, U201.62
/ADAU1452/ADCIN_SDATA2: R524.2, U201.67
/ADAU1452/ADCIN_SDATA3: R520.2, U201.70
/ADAU1452/AVDD: C267.1, C268.1, R244.1, R246.1, U201.7
/ADAU1452/DACOUT_BCLK0: R554.1, U201.40
/ADAU1452/DACOUT_BCLK1: R558.1, U201.43
/ADAU1452/DACOUT_BCLK2: R562.1, U201.48
/ADAU1452/DACOUT_BCLK3: R566.1, U201.51
/ADAU1452/DACOUT_LRCLK0: R553.1, U201.39
/ADAU1452/DACOUT_LRCLK1: R557.1, U201.42
/ADAU1452/DACOUT_LRCLK2: R561.1, U201.47
/ADAU1452/DACOUT_LRCLK3: R565.1, U201.50
/ADAU1452/DACOUT_SDATA0: R555.1, U201.41
/ADAU1452/DACOUT_SDATA1: R559.1, U201.44
/ADAU1452/DACOUT_SDATA2: R563.1, U201.49
/ADAU1452/DACOUT_SDATA3: R567.1, U201.52
/ADAU1452/DSP_RESET: C243.1, R226.1, U201.24
/ADAU1452/DVDD: C206.1, C207.1, C208.1, C209.1, C210.1, C211.1, C212.1, C213.1, C215.1, C217.1, C219.1, C221.1, C222.1, C223.1, C226.1, C227.1, C228.1, C229.1, C230.1, L201.2, R202.1, U201.20, U201.35, U201.53, U201.71
/ADAU1452/GLB_RESET: R231.1, R587.2, TP206.1
/ADAU1452/I2C_SCL: P506.1, R210.1
/ADAU1452/I2C_SDA: P506.3, R209.1
/ADAU1452/IOVDD: C232.1, C234.1, C235.1, C237.1, C238.1, C240.1, C241.1, C242.1, C244.1, C245.1, C246.1, C247.1, C248.1, C249.1, L203.2, R224.1, U201.2, U201.18, U201.38, U201.56, U203.5
/ADAU1452/MAN_RST_IN: C239.1, P202.1, R225.2, R541.2, SW201.1
/ADAU1452/MCLK: R235.1, U501.5
/ADAU1452/MCLK2: R234.1, U502.5
/ADAU1452/MCLK_ADAU: R233.2, U201.23
/ADAU1452/MISO/SDA: R204.2, R209.2, R211.2, U201.30
/ADAU1452/MOSI/ADDR1: R205.2, R207.2, R213.2, U201.32
/ADAU1452/M_SS: R230.2, R238.2, U204.1
/ADAU1452/PVDD: C224.1, C225.1, C251.1, C252.1, C257.1, C258.1, C260.1, L202.2, R237.1, U201.15
/ADAU1452/SCLK/SCL: R203.2, R210.2, R212.2, U201.31
/ADAU1452/SELFBOOT: JP201.1, R201.2, U201.34
/ADAU1452/SPI_MISO: P506.5, P511.2, R211.1
/ADAU1452/SPI_MOSI: P506.8, P511.6, R213.1
/ADAU1452/SPI_SCLK: P506.7, P511.4, R212.1
/ADAU1452/SPI_SS: P506.9, P511.8, R214.1
/ADAU1452/SS/ADDR0: R206.2, R208.2, R214.2, U201.33
/ADAU1452/XTALIN: C254.1, R243.1, R245.1, U201.21, X201.1
/ADAU1452/XTALOUT: R241.1, U201.22
/Connectors/AUXADCIN_1: D501.1, D502.2, R535.2, U201.8
/Connectors/AUXADCIN_2: D503.1, D504.2, R536.2, U201.9
/Connectors/AUXADCIN_3: D505.1, D506.2, R537.2, U201.10
/Connectors/AUXADCIN_4: D507.1, D508.2, R538.2, U201.11
/Connectors/AUXADCIN_5: D509.1, D510.2, R539.2, U201.12
/Connectors/AUXADCIN_6: D511.1, D512.2, R540.2, U201.13
/Connectors/I2C_RST: P506.6, P511.12, R541.1
/Connectors/MCLKA1: R529.2, R546.1
/Connectors/MCLKA2: R525.2, R545.1
/Connectors/MCLKA3: R521.2, R544.1
/Connectors/MCLKA4: R517.2, R547.1
/Connectors/MCLKB1: R551.1, R552.1
/Connectors/MCLKB2: R550.1, R556.1
/Connectors/MCLKB3: R549.1, R560.1
/Connectors/MCLKB4: R548.1, R564.1
/Connectors/M_MUTE: P512.12, R248.2
/Connectors/M_SPI_MISO: R227.1, R586.2, U201.29
/Connectors/M_SPI_MOSI: P512.6, R229.2, U204.5
/Connectors/M_SPI_SCLK: P512.4, R228.2, U204.6
/Connectors/M_SPI_SS: P512.8, R236.2
/Power Supply/2V1: C313.1, C315.1, C317.1, C320.1, C322.1, C324.1, D306.2, L302.2, R304.2, U303.3
GNDD: C201.2, C205.2, C206.2, C207.2, C208.2, C209.2, C210.2, C211.2, C212.2, C213.2, C214.2, C215.2, C216.2, C217.2, C218.2, C219.2, C220.2, C221.2, C222.2, C223.2, C226.2, C227.2, C228.2, C229.2, C230.2, C231.2, C232.2, C233.2, C234.2, C235.2, C236.2, C237.2, C238.2, C239.2, C240.2, C241.2, C242.2, C243.2, C244.2, C245.2, C246.2, C247.2, C248.2, C249.2, C250.2, C251.2, C252.2, C253.2, C254.2, C256.2, C257.2, C258.2, C260.2, C261.2, C263.2, C264.2, C265.2, C266.2, C267.2, C268.2, C301.1, C302.1, C303.2, C304.2, C305.2, C306.2, C307.2, C309.1, C310.1, C311.1, C312.1, C313.2, C314.2, C315.2, C316.2, C317.2, C318.2, C319.2, C320.2, C321.2, C322.2, C323.2, C324.2, C325.2, C326.2, C327.2, C328.2, C329.2, C333.2, C334.2, C336.2, C337.2, C338.2, C339.2, C401.2, C402.2, C403.2, C404.2, C405.2, C406.2, C407.2, C408.2, C410.2, C411.2, C412.2, C413.2, C414.2, C501.2, C502.2, C503.2, C504.2, C505.2, C506.2, CN401.2, CN402.2, D302.1, D304.2, D305.1, D307.1, D502.1, D504.1, D506.1, D508.1, D510.1, D512.1, JP201.2, P202.2, P203.1, P203.3, P304.2, P306.2, P307.2, P501.1, P501.3, P501.5, P501.7, P501.9, P501.10, P502.1, P502.3, P502.5, P502.7, P502.9, P502.10, P503.1, P503.3, P503.5, P503.7, P503.9, P503.10, P504.1, P504.3, P504.5, P504.7, P504.9, P504.10, P505.1, P505.3, P505.5, P505.7, P505.9, P505.11, P506.10, P507.1, P507.3, P507.5, P507.7, P507.9, P507.10, P508.1, P508.3, P508.5, P508.7, P508.9, P508.10, P509.1, P509.3, P509.5, P509.7, P509.9, P509.10, P510.1, P510.3, P510.5, P510.7, P510.9, P510.10, P511.1, P511.3, P511.5, P511.7, P511.9, P511.11, P512.1, P512.3, P512.5, P512.7, P512.9, P512.11, R207.1, R208.1, R220.1, R221.1, R222.1, R223.1, R232.1, R243.2, R302.1, R306.1, R408.1, R412.1, R413.1, R501.1, R502.1, R503.1, R504.1, R505.1, R506.1, R507.1, R508.1, R509.1, R510.1, R511.1, R512.1, R513.1, R514.1, R515.1, R516.1, R568.1, R569.1, R570.1, R571.1, R572.1, R573.1, R574.1, R575.1, R576.1, R577.1, R578.1, R579.1, R580.1, R581.1, R582.1, R583.1, SW201.2, TP513.1, TP514.1, TP515.1, TP516.1, U201.1, U201.6, U201.14, U201.17, U201.19, U201.25, U201.36, U201.37, U201.54, U201.55, U201.72, U201.EP1, U202.4, U203.2, U204.4, U301.2, U302.1, U303.1, U401.2, U402.2, U403.3, U404.7, U501.4, U502.4
unnamed: C205.1, R202.2
unnamed: C214.1, R215.2
unnamed: C216.1, C218.1, C220.1, R215.1, R247.1, U202.8
unnamed: C224.2, R219.1
unnamed: C225.2, R219.2, U201.16
unnamed: C231.1, R224.2
unnamed: C233.1, R225.1, U202.7
unnamed: C236.1, R226.2, R231.2, R232.2, U202.5
unnamed: C250.1, R237.2
unnamed: C261.1, R241.2, X201.2
unnamed: C265.1, R246.2
unnamed: C304.1, R303.2
unnamed: C308.1, U301.1
unnamed: C308.2, D302.2, L302.1, U301.6
unnamed: C327.1, R311.2
unnamed: C329.1, C337.1, P306.1, P307.1, R310.1, R311.1
unnamed: C401.1, R401.2
unnamed: C402.1, C403.1, C404.1, C405.1, C406.1, C407.1, C408.1, C410.1, C411.1, C412.1, C413.1, C414.1, L401.2, R401.1, R402.1, U401.5, U402.1, U403.2, U404.14
unnamed: C415.1, R404.2
unnamed: C415.2, R402.2, U402.3
unnamed: C416.1, R410.2
unnamed: C416.2, U404.8, U404.10, U404.12
unnamed: C417.1, R411.2
unnamed: C417.2, CN402.1, R413.2
unnamed: C501.1, R533.2
unnamed: C502.1, C503.1, R533.1, R542.2, R584.2, U501.1
unnamed: C504.1, R534.2
unnamed: C505.1, C506.1, R534.1, R543.2, R585.2, U502.1
unnamed: CN401.1, R410.1, R412.2
unnamed: D301.1, P304.1
unnamed: D301.2, L301.1
unnamed: D304.1, R309.2
unnamed: JP401.1, R404.1
unnamed: JP401.3, R407.2
unnamed: P203.2, R245.2
unnamed: P501.2, R513.2, R517.1
unnamed: P501.4, R509.2, R518.1, TP501.1
unnamed: P501.6, R505.2, R519.1, TP505.1
unnamed: P501.8, R501.2, R520.1, TP506.1
unnamed: P502.2, R514.2, R521.1
unnamed: P502.4, R510.2, R522.1, TP502.1
unnamed: P502.6, R506.2, R523.1, TP507.1
unnamed: P502.8, R502.2, R524.1, TP508.1
unnamed: P503.2, R515.2, R525.1
unnamed: P503.4, R511.2, R526.1, TP503.1
unnamed: P503.6, R507.2, R527.1, TP509.1
unnamed: P503.8, R503.2, R528.1, TP510.1
unnamed: P504.2, R516.2, R529.1
unnamed: P504.4, R512.2, R530.1, TP504.1
unnamed: P504.6, R508.2, R531.1, TP511.1
unnamed: P504.8, R504.2, R532.1, TP512.1
unnamed: P505.2, R535.1
unnamed: P505.4, R536.1
unnamed: P505.6, R537.1
unnamed: P505.8, R538.1
unnamed: P505.10, R539.1
unnamed: P505.12, R540.1
unnamed: P507.2, R552.2, R580.2
unnamed: P507.4, R553.2, R576.2, TP517.1
unnamed: P507.6, R554.2, R572.2, TP521.1
unnamed: P507.8, R555.2, R568.2, TP522.1
unnamed: P508.2, R556.2, R581.2
unnamed: P508.4, R557.2, R577.2, TP518.1
unnamed: P508.6, R558.2, R573.2, TP523.1
unnamed: P508.8, R559.2, R569.2, TP524.1
unnamed: P509.2, R560.2, R582.2
unnamed: P509.4, R561.2, R578.2, TP519.1
unnamed: P509.6, R562.2, R574.2, TP525.1
unnamed: P509.8, R563.2, R570.2, TP526.1
unnamed: P510.2, R564.2, R583.2
unnamed: P510.4, R565.2, R579.2, TP520.1
unnamed: P510.6, R566.2, R575.2, TP527.1
unnamed: P510.8, R567.2, R571.2, TP528.1
unnamed: P512.2, R586.1
unnamed: P512.10, R587.1
unnamed: R216.2, R220.2, U202.1
unnamed: R217.2, R221.2, U202.2
unnamed: R218.2, R222.2, U202.3
unnamed: R223.2, U201.3
unnamed: R227.2, R239.2, U204.2
unnamed: R228.1, U201.28
unnamed: R229.1, U201.27
unnamed: R230.1, U201.26
unnamed: R233.1, U203.1, U203.3
unnamed: R234.2, U203.6
unnamed: R235.2, U203.4
unnamed: R236.1, U201.46
unnamed: R240.2, U204.3
unnamed: R242.2, U204.7
unnamed: R248.1, U201.45
unnamed: R301.1, R302.2, U301.4
unnamed: R304.1, R305.2, U301.3
unnamed: R305.1, R306.2
unnamed: R403.1, U401.1, U401.3
unnamed: R405.1, U404.5
unnamed: R405.2, U401.4
unnamed: R406.1, U401.6
unnamed: R406.2, U403.1
unnamed: R407.1, U404.4
unnamed: R408.2, R409.1, U404.2, U404.3
unnamed: R409.2, R411.1, U404.1
unnamed: R542.1, U501.8
unnamed: R543.1, U502.8
unnamed: R544.2, U501.2
unnamed: R545.2, U501.3
unnamed: R546.2, U501.6
unnamed: R547.2, U501.7
unnamed: R548.2, U502.2
unnamed: R549.2, U502.3
unnamed: R550.2, U502.6
unnamed: R551.2, U502.7
unnamed: TP201.1, U202.6
unnamed: TP204.1, U201.64
unnamed: TP205.1, U201.63
unnamed: U404.6, U404.9, U404.11, U404.13
VAA: C201.1, C253.1, C256.1, C263.1, C264.1, C266.1, C314.1, C316.1, C318.1, C319.1, C321.1, C323.1, C325.1, C326.1, C328.1, D303.1, D305.2, D501.2, D503.2, D505.2, D507.2, D509.2, D511.2, L202.1, L203.1, L401.1, R201.1, R203.1, R204.1, R205.1, R206.1, R216.1, R217.1, R238.1, R239.1, R240.1, R242.1, R244.2, R247.2, R301.2, R310.2, R584.1, R585.1, U204.8, U302.2
VCC: C301.2, C302.2, C303.1, C305.1, C306.1, C307.1, C309.2, C310.2, C311.2, C312.2, D303.2, L301.2, R303.1, R309.1, U301.5, U302.3
VDD: C333.1, C334.1, C336.1, C338.1, C339.1, D306.1, D307.2, L201.1, R218.1, U303.2

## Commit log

2016-01-24 Release 1.0
    Release 1.0
    [ADAU1452 PSU.sch, ADAU1452.sch, ClockFanout.sch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]
2016-05-26 Revision 2.0
    [ADAU1452 PSU.sch, ADAU1452.sch, ClockFanout.sch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]
2016-07-01 Revision 2.0
    Update BOM sheet name
    [DSP-ADAU1452-2.0-Bill-of-Materials.ods]
2025-09-12 KiCad 9.04
    Updated to KiCad 9.04

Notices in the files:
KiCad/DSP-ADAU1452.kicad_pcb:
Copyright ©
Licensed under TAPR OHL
